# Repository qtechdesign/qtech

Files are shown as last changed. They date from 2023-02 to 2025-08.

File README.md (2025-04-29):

## [FPS | Frost Protection System](https://qtech.hr/en/pages/sustav)

Frost

## Mission

The mission of the Frost Protection System (FPS) is to enable sustainable food and biosystem production through the integration of software and hardware solutions. FPS enables farmers to maximize their yields while minimizing costs by collecting system, time, and production data from various micro-locations and using smart analytics to improve production characteristics. With its focus on the user, continuous improvement, and technical innovation, FPS is uniquely positioned for rapid growth. 

We strive to foster development and create an innovative work environment through the implementation of new business process management systems. We also aim to adopt an agile scrum methodology throughout the entire life cycle of FPS. 

We are committed to continuously creating innovative technical solutions that improve our system. We also strive to use new technologies in a way that positively impacts our global climate.

## Vision

Our vision for the Frost Protection System (FPS) is to create an open source platform that enables efficient, sustainable and environmentally-friendly food production by leveraging innovative technologies. We strive to empower farmers, researchers, and consumers to make informed decisions about their food production and consumption by providing them with access to real-time data on weather conditions and frost protection systems. Through collaboration, we will continue to develop our platform and create a future where food production is both efficient and sustainable.

frost problem

## Motivation

In the past five years, climate change analysis and monitoring of the open-air food production cycle have revealed an increased occurrence of early spring frosts, which has a significant impact on crop yields. Frost events often result in complete yield losses for the upcoming season, which cannot be fully covered by crop insurance. Therefore, active measures to protect and reduce the risk of food production are necessary. One such protective measure is a frost protection system (through irrigation) based on the phenomenon of water anomaly, wherein energy is released when water changes from liquid to solid state. This energy is used to maintain flower and fruit temperatures between 0-2°C. During such protection of crops, an ice crust forms over flowers and fruits with temperature at 0°C that protects them through insulation effect. Modern frost protection systems employ technology to create air saturated with moisture (100% relative humidity) within the protected microclimate that results in significant savings in water requirements during protection since it eliminates evaporation and saves energy required for maintaining thin layer ice crystals at 0°C. Further advancement in technology requires dynamic operation model for the system with varying intensity of irrigation depending on current weather conditions. The reason behind this requirement is to maintain crystal structure of ice (transparent ice) under optimal water consumption throughout night for protecting fruits from negative external temperatures. Parameters that could affect crystal structure of ice are temperature, humidity, wind and intensity of irrigation with droplet size being considered as well. The main objective of this project is to analyze influence parameters on thickness and transparency of protective ice constructions. The obtained results would serve as basis for development advanced management system for frost protection as well as new types sprayers with variable intensity irrigation

# System description

technology FPS

## Multisensor node

The Frost Protection System (FPS) Multisensor is a device designed to provide real-time data on weather conditions and frost protection systems. The device features an integrated solar regulator for 12V battery charging, and operates on 5V power. It can collect data from multiple sensors every 3 minutes, and can also be set to sleep mode between readings. The Multisensor is optimized to consume low amounts of power, making it suitable for use in low voltage devices (above 12V). With its user-friendly interface and easy setup, the FPS Multisensor is the perfect solution for monitoring weather conditions and improving yields.

## Communication device

The Frost Protection System (FPS) Communication Device is a secure and reliable gateway that enables the transmission of data between nodes and the cloud. It uses a private LoRa network to provide wireless communication over a radius of up to 10 km, depending on local radio equipment regulations. This device can be easily installed in any micro-location, and it allows farmers to maximize their yields while minimizing costs by collecting system, time, and production data from various micro-locations. With its focus on user experience, technical innovation, and continuous improvement, FPS Communication Device is uniquely positioned for rapid growth.

## Cloud device

The Frost Protection System (FPS) Cloud Device is a comprehensive microclimate solution for agricultural production. The device collects and stores data from various micro-locations, such as temperature, humidity, light intensity, and soil moisture, to provide farmers with real-time insights into their production environment. The device is powered by a secure cloud platform that is compliant with GDPR regulations and designed for optimal cyber security. Data is collected and transmitted securely using encrypted protocols to ensure that the data is not intercepted or tampered with during transmission. With its user-friendly interface and intuitive analytics, FPS Cloud Device allows farmers to make informed decisions about their crop production in order to maximize yields while minimizing costs.

## [PIP 2.0](https://qtech.hr/en/products/pip-pulsator-2-0)

PIP 2.0

PIP 2.0 sprayer kit is the best ratio of water energy consumption and rainfall efficiency on the protected surface of the frost protection system. The sprayer has a rainfall range of 5 meters at a pressure of 1 bar (water column 10 m). Uniform water flow in the range of 1-4 bar (water column 10--40m). Pulsating sprayer PIP 2.0 ensures a constant rainfall intensity in the range of 1.2-2.0 mm / m2 / h (depending on the installation microlocation and the design of the frost protection system, a grid on which pulsators are placed is defined).

## Fog

fog

Introducing hot air into the system can produce a fog, but it depends on the specific system and the conditions in which the hot air is introduced. In a frost protection system, the goal is to create a microclimate with 100% relative humidity to protect crops from frost damage. This is typically achieved by using irrigation to create a mist or fog that surrounds the crops and maintains the temperature above freezing. If hot air is introduced into the system, it can raise the temperature and reduce the relative humidity, which would make it less effective at protecting crops from frost. 

Introducing the underground hot air at 100% relative humidity (RH) and a temperature around 8°C into an orchard microclimate with -10°C and 95% RH would create a fog. The hot air would cause the temperature in the orchard to rise, and the high humidity would cause the air to reach 100% relative humidity. As the air temperature rises and the humidity increases, the difference between the air temperature and the dew point temperature will decrease, which will cause the air to cool to its dew point temperature. This cooling process will cause the water vapor in the air to condense into droplets, creating a fog.

The fog would help to protect the crops from frost damage by maintaining a higher temperature around the crops, and by creating a protective layer of ice on the crops. The fog would also help to maintain a high relative humidity, which would prevent water droplets from evaporating before they reach the crops.

However, it's important to note that the success of this method would depend on the specific system, weather conditions, and the type of crops you are protecting. It would be best to contact us to discuss possible system integration.

# [Drvoplast | Maslačak](https://drvoplast.com/)

Maslačak is a web platform developed by Qtech in partnership with FMENA and the University of Zagreb. The platform aims to increase the competitiveness of production in the Republic of Croatia by applying advanced technologies, IRI activities, and establishing high standards of environmental acceptability of production.

Through the use of innovative technology, the platform aims to improve the efficiency of the agricultural sector and promote sustainable agricultural production. This will be achieved through the use of advanced technologies such as precision farming and weather forecasting, as well as the implementation of R&D activities to optimize crop yields and reduce environmental impact.

The platform also aims to establish high standards of environmental acceptability of production, which will indirectly promote sustainable agricultural production and more efficient operations of the agricultural sector.

In addition to this, Maslačak also accepts donations in Bitcoin, the address for donations is bc1q2pds7sj3per9le4362v3vu43dxucjh5vjkg9mc

The platform is aligned with the goal of [FSB | R&D](https://trello.com/b/gbMGnvT7/fsb-rd) which is to research and develop new technologies and methods to improve the agricultural sector.

Maslačak

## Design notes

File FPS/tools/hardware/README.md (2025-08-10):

# Hardware directory

Contents
- `PCB` — quick index for PCB projects, build, and assembly notes
- `Calibration.md` — photos link and calibration checklists
- `FPS_v3.0/` — current controller v4.0 and MPPT v3.0 Altium projects
- `FPS_v2.0/` — legacy designs and outputs
- `3D model/` — mechanical STEP and related assets

Quick links
- Controller project: `FPS_v3.0/WS_QTD_v4.0/WS_QTD_v4.0.PrjPcb`
- MPPT project: `FPS_v3.0/WS_MPPT_Board/WS_MPPT_Board.PrjPcb`
- Calibration album: https://photos.app.goo.gl/msPYUroQLh4XpNES6

Notes
- See `PCB` for DRC, fabrication, and assembly details
- See `NOTE_CHANGE_PIN.txt` for pin changes applied in Qtech 3.0

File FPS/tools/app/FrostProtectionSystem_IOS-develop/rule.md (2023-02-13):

{
  "rules": {
    "users" : {
      "$user_id": {
        ".read": "$user_id == auth.uid",
        ".write": "$user_id == auth.uid && newData.hasChildren(['user_name', 'email'])",
        "user_name": {
          ".validate": "newData.isString() && newData.val() != ''"
        },
        "email": {
          ".validate": "auth.token.email === newData.val()",
        },
        "gateways": {
          ".validate": "newData.hasChildren()",
          "$gateway_id": {
          	".validate": "newData.parent().parent().parent().parent().child('gateways').child($gateway_id).child('owner').val() == $user_id &&
            newData.hasChildren(['name'])",
            "name": {
              ".validate": "newData.val() == newData.parent().parent().parent().parent().parent().child('gateways').child($gateway_id).child('name').val()"
            },
            "devices": {
              ".validate": "newData.hasChildren()",
              "$device_id": {
                ".validate": "newData.parent().parent().parent().parent().parent().parent().child('gateways').child($gateway_id).child('devices').child($device_id).exists() && newData.isString()"
              }
            },
            "$other": { ".validate": false }
          }
        },
        "$other": { ".validate": false }
      }
    },
    "gateways" : {
      "$gateway_id": {
        ".read": "auth.uid == data.child('owner').val()",
        ".write": "(newData.hasChildren(['name','owner'])
        && (!data.child('owner').exists()
            || data.child('owner').val() == ''
            || data.child('owner').val() == auth.uid
            || newData.child('owner').val() == auth.uid))
        || !newData.exists()
        		&& data.child('owner').val() == auth.uid
        		&& !newData.parent().parent().child('users').child(data.child('owner').val()).child('gateways').child($gateway_id).exists() ",
        "public_key": { ".validate": "newData.isString()" },
        "name": { ".validate": "newData.isString()" },
        "GPS": {
          ".validate": "newData.hasChildren(['lat','long'])",
           "lat": { ".validate": "newData.isNumber()" },
           "long": { ".validate": "newData.isNumber()" },
        },
        "owner": {
          ".validate": "newData.parent().parent().parent().child('users').child(newData.val()).child('gateways').child($gateway_id).exists() &&
          (!data.exists() || !newData.parent().parent().parent().child('users').child(data.val()).child('gateways').child($gateway_id).exists())"
        },
        "command": { ".validate": "newData.isString()" },
        "devices": {
          ".validate": "newData.hasChildren()",
          "$device_id": {
            ".validate": "newData.hasChildren()",
            "lora_id": { ".validate": true },
            "TS": { ".validate": true },
            "name": { ".validate": true },
            "on": { ".validate": true },
            "GPS": { ".validate": true },
            "$other": { ".validate": false },
          }
        },
        "last_login": { ".validate": true },
        "$other": { ".validate": false },
      }
    },
    "devices" : {
      ".read": "auth != null",
      ".write": "auth != null",
      "$device_id": {
        ".validate": "newData.hasChildren()",
        "GPS": {
          ".validate": "newData.hasChildren(['lat','long'])",
           "lat": { ".validate": "newData.isNumber()" },
           "long": { ".validate": "newData.isNumber()" },
        },
        "name": { ".validate": "newData.isString()" },
        "lora_id": { ".validate": true },
        "owner": {
          ".validate": "newData.parent().parent().parent().child('gateways').child(newData.val()).child('devices').child($device_id).exists() &&
          (!data.exists() || !newData.parent().parent().parent().child('gateways').child(newData.val()).child('devices').child($device_id).exists())"
        },
        "owner_public_key": { ".validate": "newData.isString()" },
        "public_key": { ".validate": "newData.isString()" },
        "current_data": {
          ".validate": "newData.hasChildren()"
        },
        "$other": { ".validate": false },
      }
    },
  	"device_logs" : {
      ".read": "auth != null",
      ".write": "auth != null",
      "$device_id": {
        ".indexOn": ["TS"]
			}
    },
    "key": {
      ".read": true,
      ".write": false,
    },
    "$other": {
      ".read": false,
      ".write": false
    }
  }
}

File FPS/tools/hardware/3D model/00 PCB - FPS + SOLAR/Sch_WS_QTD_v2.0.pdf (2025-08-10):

GND | R¹ | 1%10k

# EBYTE

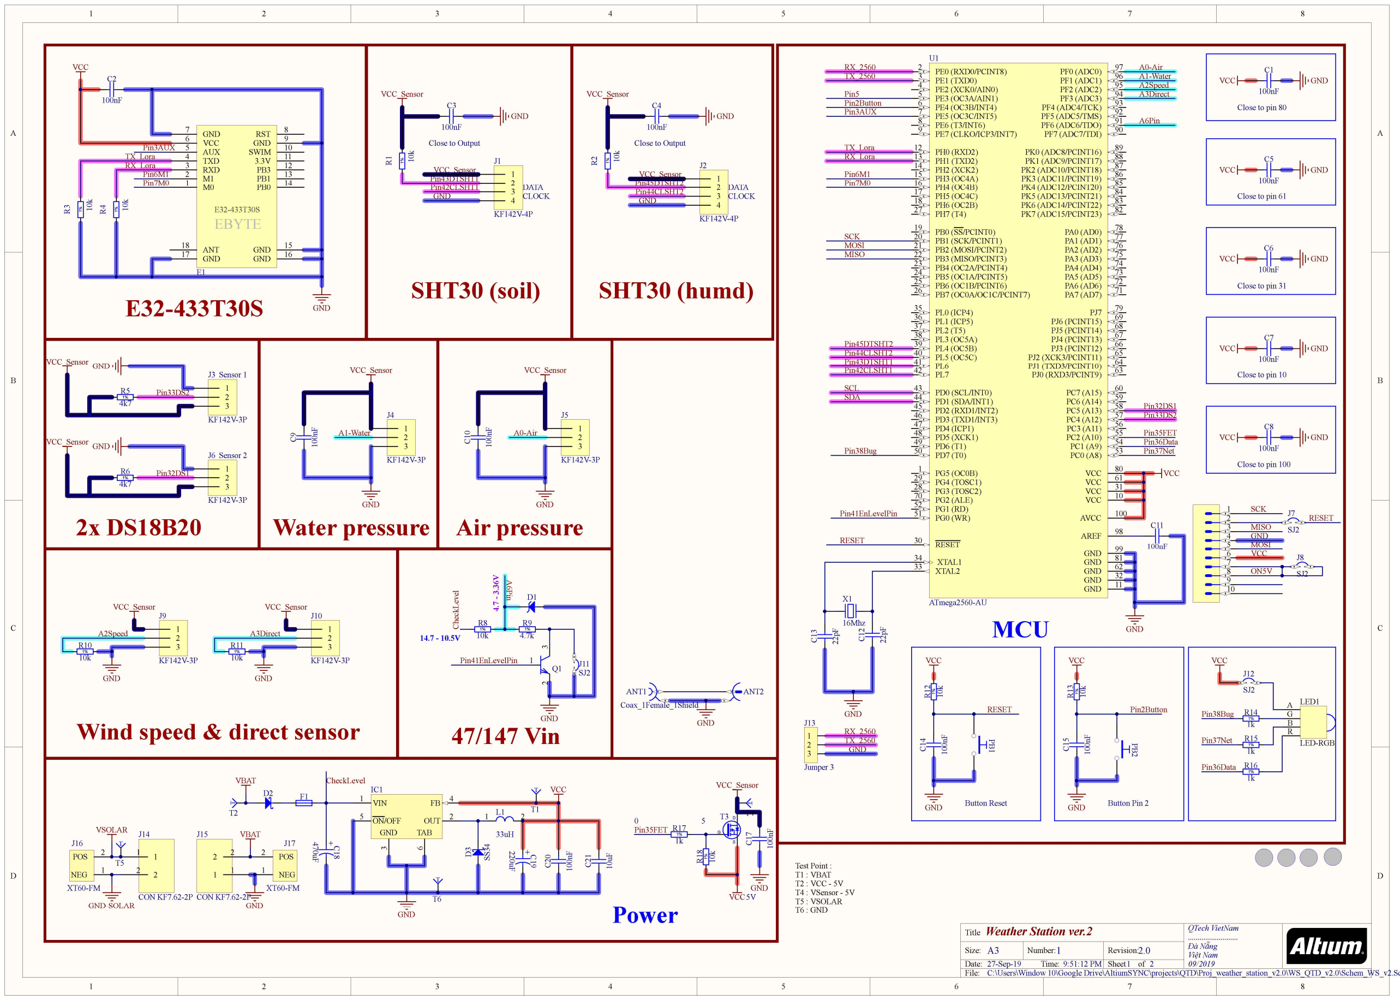
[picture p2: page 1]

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
QTech VietNam
Đà Nẵng
Việt Nam
2 09/2019

## Weather Station ver.2

1 2.0
27-Sep-19 | 9:51:12 PM
C:\Users\Window 10\Google Drive\AltiumSYNC\projects\QTD\Proj_weather_station_v2.0\WS_QTD_v2.0\Schem_WS_v2.SchDoc

Title

Size: | Number:
Date:
File:

Revision:
Time: | Sheet | of

A3

Pin3AUX

Pin6M1
Pin7M0

GND

VCC
C2
100nF 1% | R⁴ | 1%10k R³ | 10k

# E32-433T30S

TX_Lora
RX_Lora
PJ0 (RXD3/PCINT9) | 63
AVCC | 100
VCC | 31
GND | 11 GND | 32
GND | 81

PG5 (OC0B) 1

PD2 (RXD1/INT2) 45

RESET 30

PA4 (AD4) | 74
PA7 (AD7) | 71
PA5 (AD5) | 73
VCC | 80

XTAL1 34

PC1 (A9) | 54 PC2 (A10) | 55 PC3 (A11) | 56 PC4 (A12) | 57 PC5 (A13) | 58
PJ5 (PCINT14) | 68 PJ6 (PCINT15) | 69
AREF | 98

PD1 (SDA/INT1) 44

PB6 (OC1B/PCINT6) 25

PD3 (TXD1/INT3) 46
PD4 (ICP1) 47
PD5 (XCK1) 48
PD6 (T1) 49
PD7 (T0) 50
PF1 (ADC1) | 96
PF2 (ADC2) | 95
PC0 (A8) | 53
PA3 (AD3) | 75
PF4 (ADC4/TCK) | 93
PF5 (ADC5/TMS) | 92
PF6 (ADC6/TDO) | 91
PF7 (ADC7/TDI) | 90
PG0 (WR) 51 | PG1 (RD) 52 | PG2 (ALE) 70
PA6 (AD6) | 72

PD0 (SCL/INT0) 43

PH2 (XCK2) 14

PL2 (T5) 37
PL3 (OC5A) 38
PL4 (OC5B) 39
PL5 (OC5C) 40
PL6 41

VCC 10

XTAL2 33

PG3 (TOSC2) 28

PB5 (OC1A/PCINT5) 24

PF3 (ADC3) | 94
PA1 (AD1) | 77
PA2 (AD2) | 76

PE4 (OC3B/INT4) 6
PE5 (OC3C/INT5) 7
PE6 (T3/INT6) 8
PE7 (CLKO/ICP3/INT7) 9
PJ3 (PCINT12) | 66
PK5 (ADC13/PCINT21) | 84 PK4 (ADC12/PCINT20) | 85 PK3 (ADC11/PCINT19) | 86

PB2 (MOSI/PCINT2) 21
PB3 (MISO/PCINT3) 22
PB4 (OC2A/PCINT4) 23
PA0 (AD0) | 78
GND | 99
PK2 (ADC10/PCINT18) | 87
PJ2 (XCK3/PCINT11) | 65
PJ1 (TXD3/PCINT10) | 64

PG4 (TOSC1) 29

PF0 (ADC0) 97

PE3 (OC3A/AIN1) 5

PE2 (XCK0/AIN0) 4

PE1 (TXD0) 3

PE0 (RXD0/PCINT8) 2

PB7 (OC0A/OC1C/PCINT7) 26

PB1 (SCK/PCINT1) 20 PB0 (SS/PCINT0) 19

PH1 (TXD2) 13

PJ7 | 79
PJ4 (PCINT13) | 67
GND | 62
VCC | 61

PL7 42

PH0 (RXD2) 12

PH3 (OC4A) 15
PH4 (OC4B) 16
PH5 (OC4C) 17
PH6 (OC2B) 18
PH7 (T4) 27 | PK6 (ADC14/PCINT22) | 83
PK1 (ADC9/PCINT17) | 88 PK0 (ADC8/PCINT16) | 89

PL0 (ICP4) 35

PK7 (ADC15/PCINT23) 82

PL1 (ICP5) 36

PC6 (A14) | 59 PC7 (A15) | 60

U1

ATmega2560-AU

GND

VCC

X1

16Mhz C¹³ | 22pF | C¹² | 22pF

GND

C11

100nF

C1

100nF

C5

100nF

C6

100nF

C7

100nF

C8

100nF

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
Close to pin 80

Close to pin 61

Close to pin 31

Close to pin 10

Close to pin 100
RESET | C¹⁴ | 100nF ¹% R¹² 10k

VCC

GND

RESET

Button Reset | C¹⁵ | 100nF ¹% R¹³ 10k

VCC

GND Button Pin 2

Pin2Button

A0-Air
A1-Water
A2Speed
A3Direct

TX_Lora
RX_Lora

SCK
MOSI
MISO

RX_2560
TX_2560

VCC_Sensor GND

Pin32DS1
1%

R6
4k7

Pin3AUX

Pin5

Pin6M1

VCC_Sensor GND

Pin33DS2
1%

R5
4k7

# 2x DS18B20

VCC_Sensor

Pin42CLSHT1

Pin43DTSHT1

GND

DATA
CLOCK

# SHT30 (soil)

C3

100nF

VCC_Sensor

Close to Output

Sensor 1

Sensor 2

# Air pressure

# Wind speed & direct sensor

VCC_Sensor | VCC_Sensor
GND | GND

1%

R11
10k

1%

R10
10k
A2Speed | A3Direct

1%

R9
4.7k

1%

R8

10k A6Pin

# 47/147 Vin

14.7 - 10.5V | 4.7 ⁻ 3.36V

# MCU

GND | D³ | SS³⁴ | C²⁰ | 100nF

1 2

L1

33uH

+C18 470uF | +C19 220uF

VCC D2

VBAT

F1

# Power

VBAT

GND

Pin2Button PB1 | PB2

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
1k 1% R¹⁸ 10k

1%

R17
1k

VCC_Sensor

VCC

Pin7M0

Pin32DS1
Pin33DS2

Pin42CLSHT1

Pin43DTSHT1

# Water pressure

A1-Water

VCC_Sensor

GND

Pin38Bug | Pin37Net

Pin35FET

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
ON5V

RESET

SCK

GND

MISO

VCC

MOSI

D

S

G

T3

5V

0 5

GND

TX_2560

RX_2560

A

B

G

R

LED1

LED-RGB

J12

SJ2

Pin38Bug

Pin37Net

VSOLAR

GND-SOLAR | C²¹ | 10uF

1 3 2

Q1

GND

Pin41EnLevelPin

J7

SJ2

J8

SJ2

VCC_Sensor

Pin44CLSHT2

Pin45DTSHT2

GND

DATA
CLOCK

# SHT30 (humd)

C4

100nF

VCC_Sensor

Close to Output R² 1%10k

GND

Pin44CLSHT2

Pin45DTSHT2

A0-Air

VCC_Sensor

GND C⁹ | 100nF | C¹⁰ | 100nF

A6Pin

D1

SCL
SDA

GND 7
VCC 6
AUX 5
TXD 4
RXD 3
M1 2
M0 1
RST | 8
GND | 9
SWIM | 10
3.3V | 11
PB3 | 12
PB1 | 13
PB0 | 14

ANT 18

GND 17 | GND | 15
| GND | 16

E32-433T30S

E1

1

1

2

2

J15

CON KF7.62-2P

VIN 1

ON/OFF 5 | OUT 2

GND3

FB 4

TAB6

IC1

1

1

2

2

J14

CON KF7.62-2P

T

T1

T

T5

T

T6 | T T4

Test Point :
T1 : VBAT
T2 : VCC - 5V
T4 : VSensor - 5V
T5 : VSOLAR
T6 : GND

1
2
3

J13

Jumper 3

POS | 2
NEG | 1

J16

XT60-FM

POS 2

NEG 1

J17

XT60-FM | C¹⁷ | 100nF

GND T
T2

ANT1
Coax_1Female_1Shield

ANT2

1
2
3
4

J1

KF142V-4P

1
2
3
4

J2

KF142V-4P

1
2
3

J3

KF142V-3P

1
2
3

J6

KF142V-3P

1
2
3

J4

KF142V-3P

1
2
3

J5

KF142V-3P

1
2
3

J9

KF142V-3P

1
2
3

J10

KF142V-3P

CheckLevel | CheckLevel

J11
SJ2

Pin35FET

Pin41EnLevelPin

GND

Pin36Data

Pin36Data

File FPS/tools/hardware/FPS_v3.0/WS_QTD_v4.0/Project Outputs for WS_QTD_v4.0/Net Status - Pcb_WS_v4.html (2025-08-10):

Altium customize

# Net Status Report

Date: | | 09-Jan-21
Time: | | 7:13:06 PM
Elapsed Time: | | 00:00:00
Filename: | | D:\Google Drive\AltiumSYNC\projects\QTD\Proj_weather_station_v4.0\WS_QTD_v4.0\Pcb_WS_v4.PcbDoc
Units: | | mmmils

Nets | Layer | Length
ANT_M | Signal Layers Only | 0mils
ANT_M1 | Signal Layers Only | 0mils
AREF | Signal Layers Only | 186.821mils
AUX | Signal Layers Only | 191.795mils
BAT-VSEN | Signal Layers Only | 0mils
BAT-VSEN-Q | Signal Layers Only | 107.992mils
CLOSE1 | Signal Layers Only | 0mils
CLOSE2 | Signal Layers Only | 0mils
COM1 | Signal Layers Only | 0mils
COM2 | Signal Layers Only | 0mils
DATA-AP1 | Signal Layers Only | 188.941mils
DATA-AP2 | Signal Layers Only | 113.749mils
DATA-DS1 | Signal Layers Only | 113.749mils
DATA-DS2 | Signal Layers Only | 113.749mils
GND | Signal Layers Only | 315.593mils
GND-SOLAR | Signal Layers Only | 0mils
LED | Signal Layers Only | 186.821mils
M0 | Signal Layers Only | 108.775mils
M1 | Signal Layers Only | 186.821mils
MISO | Signal Layers Only | 188.941mils
MOSI | Signal Layers Only | 107.992mils
NetD2_1 | Signal Layers Only | 0mils
NetD4R1_2 | Signal Layers Only | 0mils
NetD4R2_2 | Signal Layers Only | 0mils
NetIC2R1_1 | Signal Layers Only | 0mils
NetIC2R2_1 | Signal Layers Only | 0mils
NetLED1_1 | Signal Layers Only | 0mils
NetLED2R1_1 | Signal Layers Only | 0mils
NetLED2R2_1 | Signal Layers Only | 0mils
NetQ2_1 | Signal Layers Only | 0mils
NetQ3R1_1 | Signal Layers Only | 0mils
NetQ3R2_1 | Signal Layers Only | 0mils
NetR7_2 | Signal Layers Only | 0mils
NetU1_19 | Signal Layers Only | 108.775mils
NetU1_22 | Signal Layers Only | 181.456mils
NetU2_10 | Signal Layers Only | 0mils
NetU2_11 | Signal Layers Only | 0mils
NetU2_12 | Signal Layers Only | 0mils
NetU2_13 | Signal Layers Only | 0mils
NetU2_14 | Signal Layers Only | 0mils
OPEN1 | Signal Layers Only | 0mils
OPEN2 | Signal Layers Only | 0mils
P12V-BAT | Signal Layers Only | 0mils
P16V-SOLAR | Signal Layers Only | 0mils
P5V-Main | Signal Layers Only | 1539.358mils
P5V-SEN | Signal Layers Only | 0mils
RESET-E32 | Signal Layers Only | 191.795mils
RL-CTL1 | Signal Layers Only | 191.795mils
RL-CTL2 | Signal Layers Only | 108.775mils
RL-CTR1 | Signal Layers Only | 0mils
RL-CTR2 | Signal Layers Only | 0mils
RST-E32 | Signal Layers Only | 0mils
RST_MCU | Signal Layers Only | 103.409mils
RXD-E32 | Signal Layers Only | 103.409mils
RXM | Signal Layers Only | 181.456mils
SCK | Signal Layers Only | 113.749mils
TXD-E32 | Signal Layers Only | 181.456mils
TXM | Signal Layers Only | 107.992mils
WAKE | Signal Layers Only | 188.941mils
XTAL1 | Signal Layers Only | 107.992mils
XTAL2 | Signal Layers Only | 188.941mils

Back to top

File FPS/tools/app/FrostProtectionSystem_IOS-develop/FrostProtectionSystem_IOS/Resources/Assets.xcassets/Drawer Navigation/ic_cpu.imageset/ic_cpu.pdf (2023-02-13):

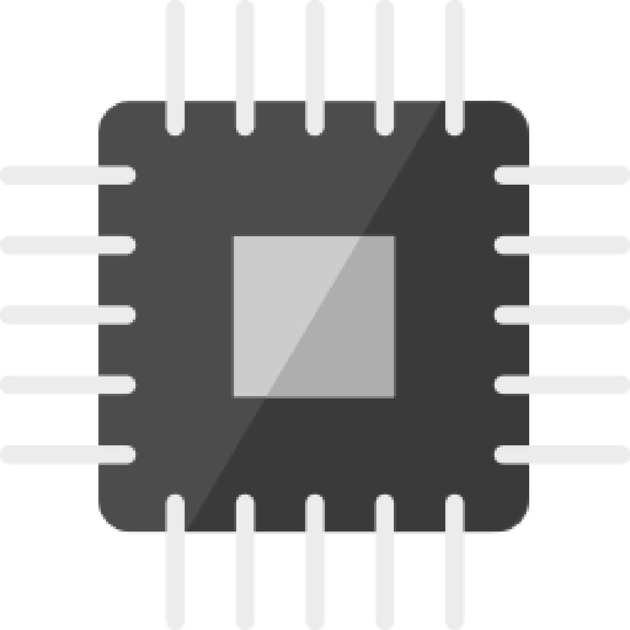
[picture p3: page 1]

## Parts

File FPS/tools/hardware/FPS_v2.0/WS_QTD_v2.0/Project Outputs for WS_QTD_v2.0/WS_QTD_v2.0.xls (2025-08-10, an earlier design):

Comment | Description | Designator | Footprint | LibRef | Quantity | 6 | Check
Coax_1Female_1Shield |  | ANT1 | HUBER-SUHNER_85 SMA-50-0-101/111 NE | HUBER-SUHNER_85_SMA-50-0-101/111_NE | 1 | 6 | ok
U.FL |  | ANT2 | HIROSE_U.FL-R-SMT-1(10) | HIROSE_U.FL-R-SMT-1(10) | 1 | 6 | ok
100nF | Non-polarised capacitor | C1, C2, C3, C4, C5, C6, C7, C8, C9, C10, C11, C14, C15, C17, C20 | CAPC1608X87N | CC0603_100NF_50V_10%_X7R | 15 | 90 | ok
22pF | Non-polarised capacitor | C12, C13 | CAPC1608X87N | CC0603_22PF_50V_5%_NP0 | 2 | 12 | ok
470uF | Polarised capacitor | C18 | CAPAE1030X1020N | CAE1030-1020_470UF_25V_20% | 1 | 6 | ok
220uF | Polarised capacitor | C19 | CAPMP6032X280N | CTE6032-28_100UF_6.3V_10%_LESR0075 | 1 | 6 | ok
10uF | Non-polarised capacitor | C21 | CAPC2012X135N | CC0805_10UF_16V_10%_X5R | 1 | 6 | ok
BZV55-B5V1 | Zener Diode | D1 | DIOMELF3515N | BZV55-B5V1 | 1 | 6 | ok
SS16 | Schottky Diode | D2 | DIOM5127X229N | SS16 | 1 | 6 | ok
SS34 | Schottky Diode | D3 | DIOM5127X229N | SS16 | 1 | 6 | ok
E32-T30S | Lora Ebyte E32-T30S Module | E1 | E32-433T30S | E32-433T30S | 1 | 6
140mA-60V | Fuse | F1 | FUSRC4632X90N | FUSR1812_TYCO-MINISMDC014F | 1 | 6 | ok
HOLE |  | HOLE1, HOLE2, HOLE3, HOLE4 | HOLE M3 | HOLE M3 | 4 | 24
LM2596 |  | IC1 | TO263-5 | LM2596-5V | 1 | 6 | ok
KF142V-4P | CON KF142V-4P-5.08 | J1, J2 | CON KF142V-4P-5.08 | CON KF142V-4P-5.08 | 2 | 12 | ok
KF142V-3P | CON KF142V-3P-5.08 | J3, J4, J5, J6, J9, J10 | CON KF142V-3P-5.08 | CON KF142V-3P-5.08 | 6 | 36 | ok
SJ2 | Solder Jump2 | J7, J8, J11, J12 | SJ2 | SJ2 | 4 | 24
Jumper 3 | Jumper 3 | J13 | JP3 | JP3 | 1 | 6
CON KF7.62-2P |  | J14, J15 | CON KF7.62-2P | CON KF7.62-2P | 2 | 12 |  | lấy ET-SDC
XT60-FM |  | J16, J17 | XT60-FM | XT60-FM | 2 | 12
Header 10 | Connector 10 Male | JTAG1 | 3M_N2510-6002RB | 3M_N2510-6002RB | 1 | 6 | ok
33uH |  | L1 | L_SMD | L_SMD 33uH | 1 | 6 | ok
LED-RGB |  | LED1 | LED-5MMRGBCA | LED-RGB | 1 | 6 | ok
Push Button | Push-Button Switch SPDT | PB1, PB2 | PB_TYCO_FSMSM |  | 2 | 12 | ok
C1815 | Q2SC1815 | Q1 | SOT23 | C1815 | 1 | 6 | ok
10k | Resistor - 1% | R1, R2, R3, R4, R8, R10, R11, R12, R13, R18 | RESC1608X55N | R0603_10K_1%_0.1W_100PPM, R0603_2M_1%_0.1W_100PPM, R0603_160R_1%_0.1W_100PPM | 10 | 60 | ok
4k7 | Resistor - 1% | R5, R6 | RESC1608X55N | R0603_4K7_1%_0.1W_100PPM | 2 | 12 | ok
4.7k | Resistor - 1% | R9 | RESC1608X55N | R0603_1M_1%_0.1W_100PPM | 1 | 6 | ok
1k | Resistor - 1% | R14, R15, R16, R17 | RESC1608X55N | R0603_1K_1%_0.1W_100PPM | 4 | 24 | ok
Test Point | Test Point Round 1x1 mm | T2, T4, T5, T6 | TP1x1r | TP R1x1 | 4 | 24
BSH203 | P-CHANNEL MOSFET WITH DIODE | T3 | SOT95P230X110-3N | BSH203 | 1 | 6 | ok
ATmega2560-AU | 8-bit AVR Microcontroller, 4.5-5.5V, 256KB Flash, 4KB EEPROM, 8KB SRAM, 86 GPIO pins, 100-pin TQFP, Industrial Grade (-40°C to 85°C), Pb-Free | U1 | TQFP100L | ATmega2560-AU | 1 | 6 | ok
16Mhz | Crystal, 32.768 KHz, -40 to 85 degC, 3.2 x 1.5 x 0.9 mm SMD | X1 | XT2 | XT2 | 1 | 6 | ok
Dây dài ipex |  |  |  |  |  | 6 | ok
 |  |  |  |  |  |  |  |  | thegioiic | 1245390
 |  |  |  |  |  |  |  |  | linhkien888 | 122500

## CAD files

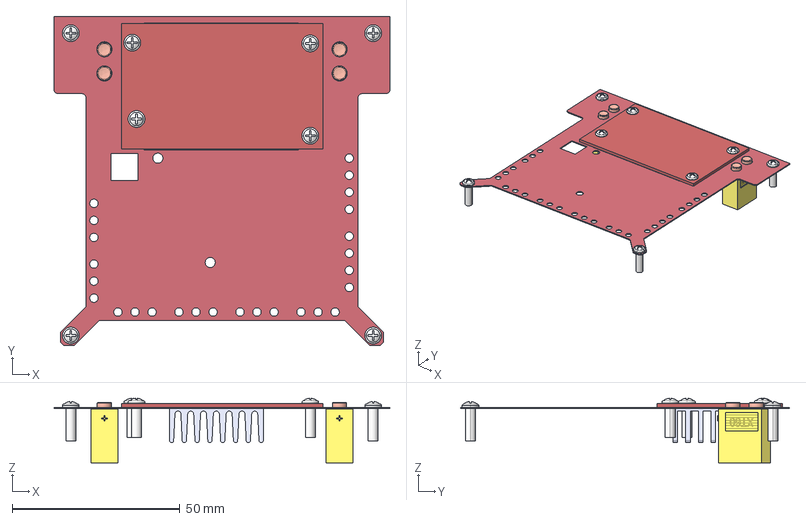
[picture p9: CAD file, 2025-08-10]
FPS/tools/hardware/3D model/00 PCB - FPS + SOLAR/Red_board.step
100.0 x 98.0 x 19.2 mm
User_Library-658-45AB
Screw-3mmX10mm x 8
Extruded
PDB_XT60_PLUG x 4

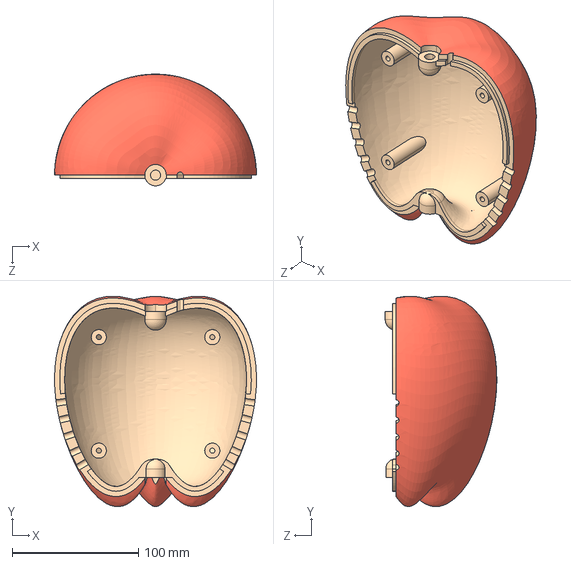
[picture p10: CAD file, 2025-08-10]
FPS/tools/hardware/3D model/Trešnja ABS/Tresnja_L.STEP
160.2 x 166.7 x 88.6 mm

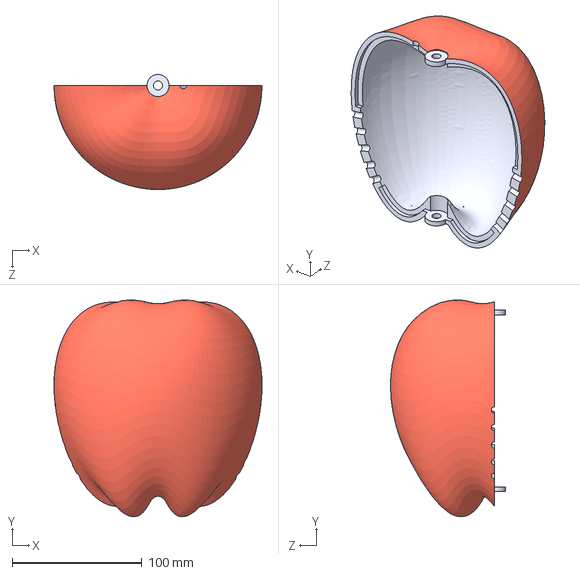
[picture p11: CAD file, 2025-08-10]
FPS/tools/hardware/3D model/Trešnja ABS/Tresnja_D.STEP
160.1 x 166.7 x 88.6 mm

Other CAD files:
FPS/tools/hardware/3D model/Trešnja ABS/Tresnja_D.SLDPRT
FPS/tools/hardware/3D model/Trešnja ABS/Tresnja_D.STL
FPS/tools/hardware/3D model/Trešnja ABS/Tresnja_L.SLDPRT
FPS/tools/hardware/3D model/Trešnja ABS/Tresnja_L.STL

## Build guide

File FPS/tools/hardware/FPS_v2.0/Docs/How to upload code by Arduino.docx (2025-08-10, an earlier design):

Open Arduino IDE and Connect Arduino to computer.

Open File > Examples > 11. ArduinoISP > ArduinoISP

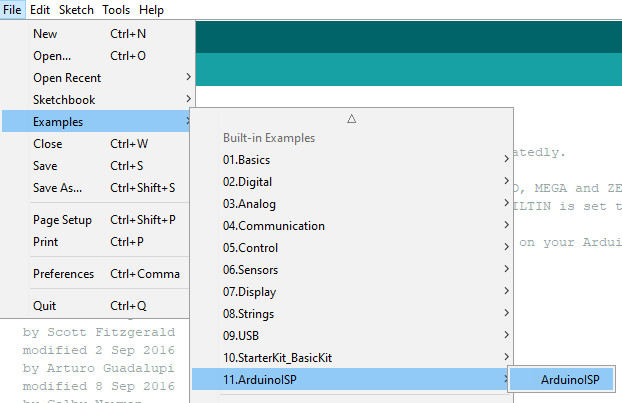
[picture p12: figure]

Choose Board : Arduino Uno and Port COM

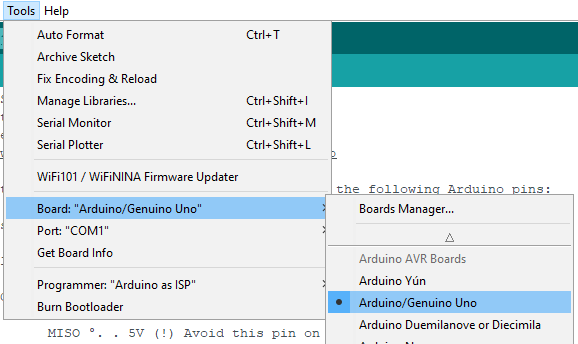
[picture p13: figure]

Upload to Arduino Uno

After upload done

Change Board : Arduino Mega 2560 and Processor : ATmega2560

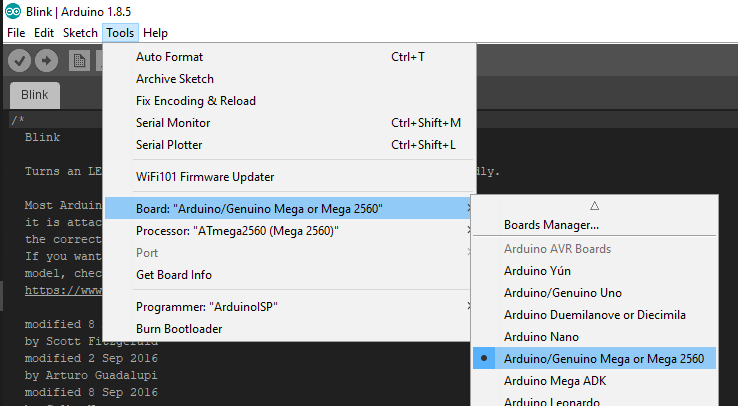
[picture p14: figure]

We use pin 10,11,12,13 (SS,MOSI,MISO,CLK) on Arduino Uno

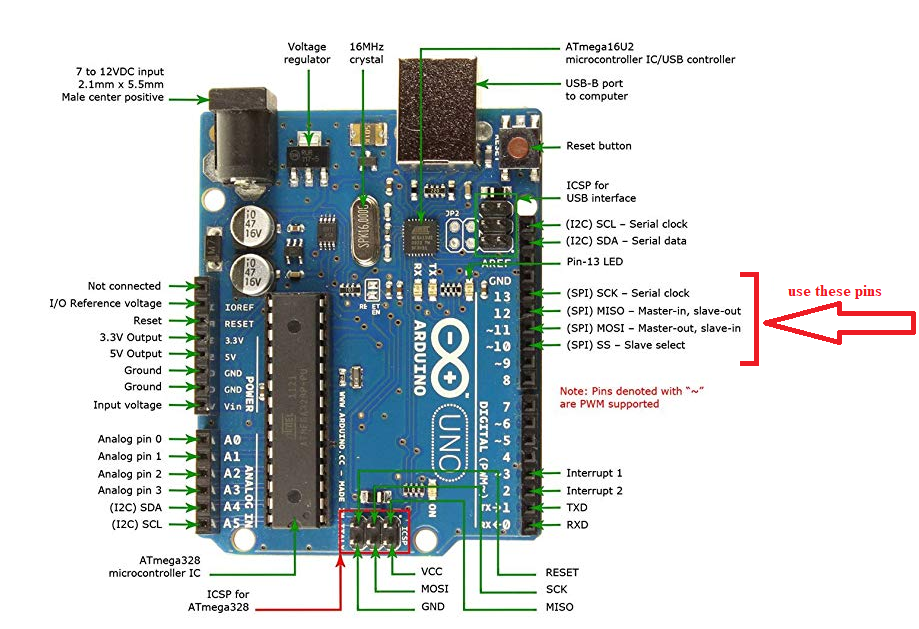
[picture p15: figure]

And connect to pins (ISP Port) on the Sensor Node

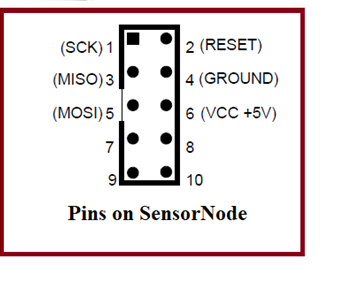
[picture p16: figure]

Connect pin on Arduino Uno to Sensor Node

MOSI ( pin 11 ) > MOSI

MISO ( pin12 ) > MISO

SCK ( pin 13 ) > SCK

SS ( pin 10 ) > RESET

VCC ( 5V ) > VCC

GND > GND

Choose Board : Arduino Mega 2560 and Processor : ATmega2560

Connect Arduino to computer

Choose Programmer : “Arduino as ISP” and Port COM

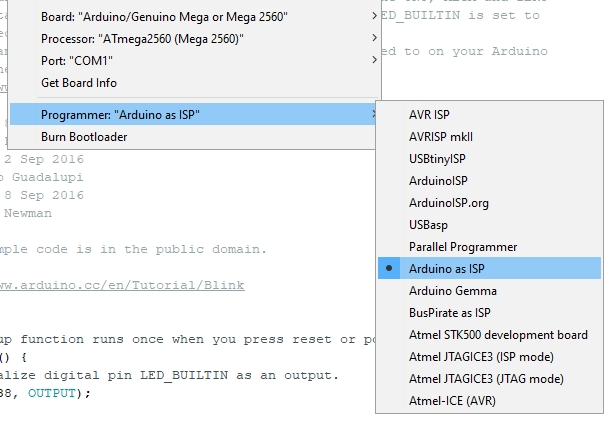
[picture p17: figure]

Then click Burn Bootloader for ATmega2560 on Sensor Node.

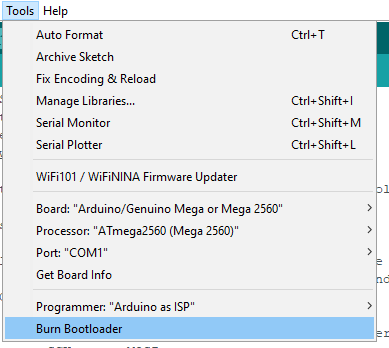
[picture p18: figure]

Wait about 30 seconds to finish

Then, Open Aruidno IDE and open (code).ino file (updated code).

You must remove ATMega328P on Arduino UNO,

be careful, foot of Atmega328 can be broken.

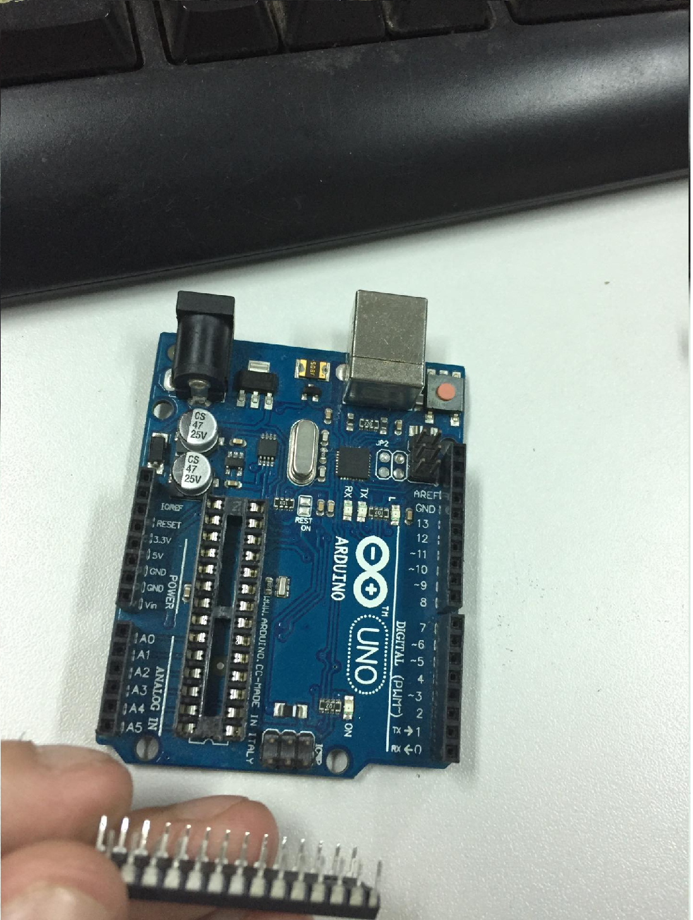
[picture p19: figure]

We use the this Arduino Board without Atmega328P

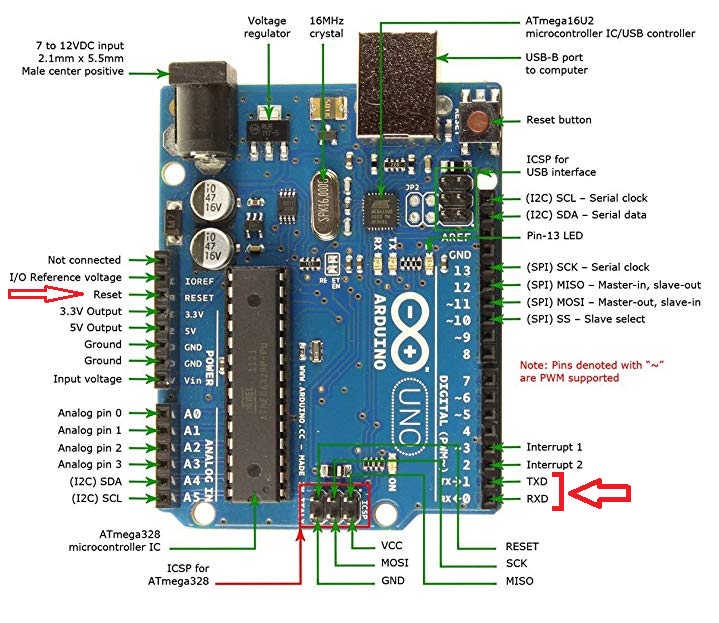
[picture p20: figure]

Connect UART pins to SensorNODE. Look 3 pins below the ISP Port.

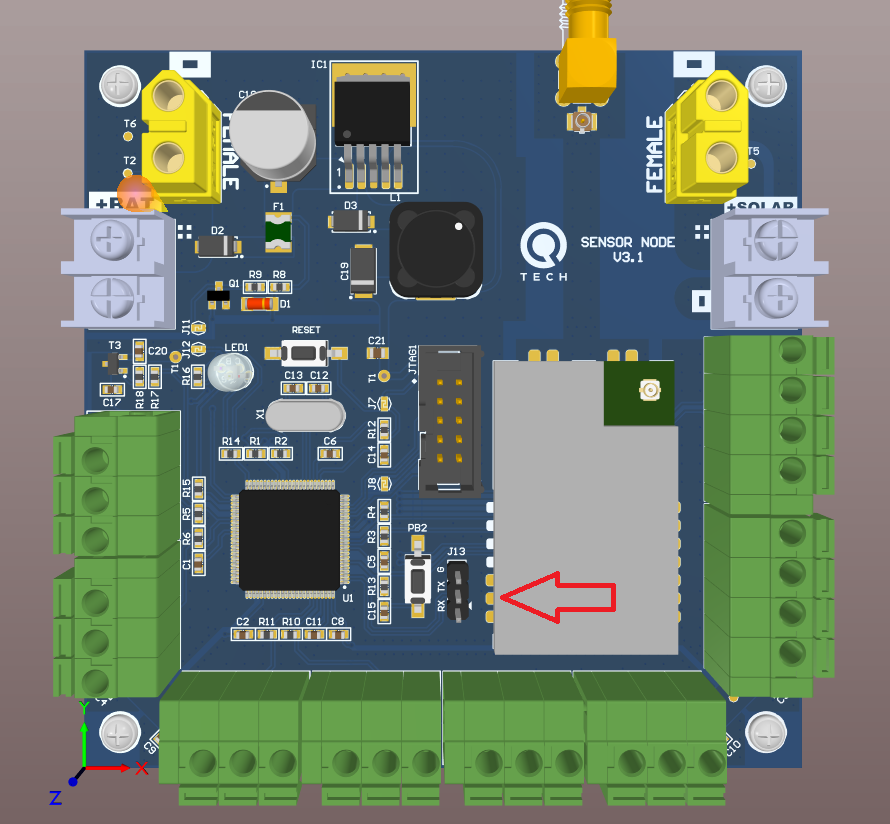
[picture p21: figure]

TX > RX

RX > TX

GND > GND

RESET > RESET (on ISP Port)

5V > 5V (on ISP Port)

Then Upload code to ATMega2560 on SensorNode

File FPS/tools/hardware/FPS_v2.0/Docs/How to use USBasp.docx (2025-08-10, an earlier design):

Follow this video to install driver for USBasp

https://www.youtube.com/watch?v=jgHIFWPUe_M

You can download Zadig at https://zadig.akeo.ie

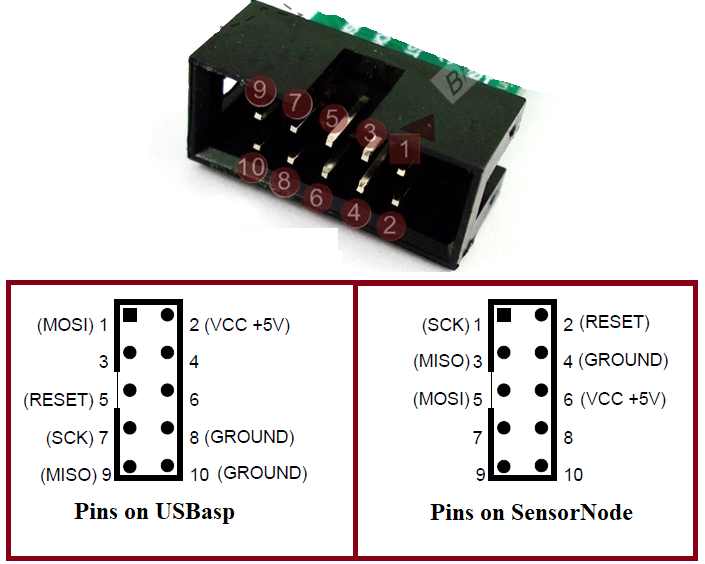
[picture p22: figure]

Connect pin on USBasp to Sensor Node

MOSI > MOSI

MISO > MISO

SCK > SCK

RESET > RESET

VCC > VCC

GND > GND

Open Aruidno IDE and open .ino file (updated code).

Choose Board : Arduino Mega 2560 and Processor : ATmega2560


Connect USBasp to computer

Choose Programmer : USBasp and Port COM

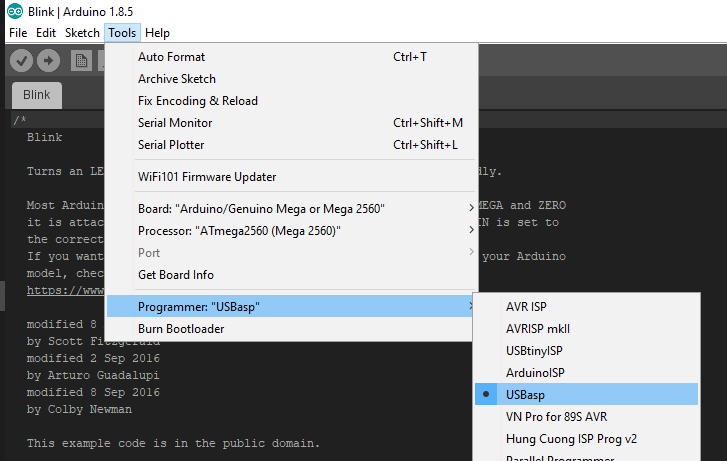
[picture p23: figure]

Then click Upload to loading code for ATmega2560 on Sensor Node.

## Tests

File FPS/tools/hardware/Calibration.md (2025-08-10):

# FPS hardware calibration and validation

Album (photos, setups, results)
- Google Photos: https://photos.app.goo.gl/msPYUroQLh4XpNES6

Scope
- Electrical bring‑up, sensor calibration, RF link checks, and environmental validation for the FPS controller (`WS_QTD_v4.0`) and `WS_MPPT_Board`.

References (design files)
- Controller: `FPS/tools/hardware/FPS_v3.0/WS_QTD_v4.0/WS_QTD_v4.0.PrjPcb`
- MPPT: `FPS/tools/hardware/FPS_v3.0/WS_MPPT_Board/WS_MPPT_Board.PrjPcb`
- Pin changes: `FPS/tools/hardware/FPS_v3.0/NOTE_CHANGE_PIN.txt`
- Datasheets: `FPS/tools/hardware/FPS_v3.0/Docs/` (ATmega2560, DS18B20, E32 LoRa, Air Pressure)

Bench setup
- Power via MPPT output or lab supply; verify polarity and fuse.
- Serial monitor on controller UART; log timestamps and measurements.
- Attach DS18B20 and air‑pressure sensors; connect LoRa module per schematic.

Checklist (bring‑up)
1) Power rails: 5 V and 3.3 V within tolerance; inrush < expected; steady‑state current noted.
2) Clock/reset: controller enumerates; boot banner visible on UART.
3) I/O pins: confirm any remaps per NOTE_CHANGE_PIN.txt.

Checklist (sensor calibration)
- DS18B20: compare to reference thermometer over 0–25 °C; accept ±0.5 °C; record offset if needed.
- Air pressure: compare to calibrated barometer; adjust slope/offset in firmware constants if drift observed.

Checklist (RF link)
- E32‑433T30S / E32‑868T20S: RSSI at 1–10 m line of sight; packet error rate under nominal conditions; antenna keep‑out respected.

Environmental validation
- Cold chamber / outdoor run: correlate measured temperature/humidity with album photos; confirm defog/frost behavior vs. expectations.

Artifacts
- Photos and setup notes: see album above.
- Logs: store alongside test date under project logs if available.

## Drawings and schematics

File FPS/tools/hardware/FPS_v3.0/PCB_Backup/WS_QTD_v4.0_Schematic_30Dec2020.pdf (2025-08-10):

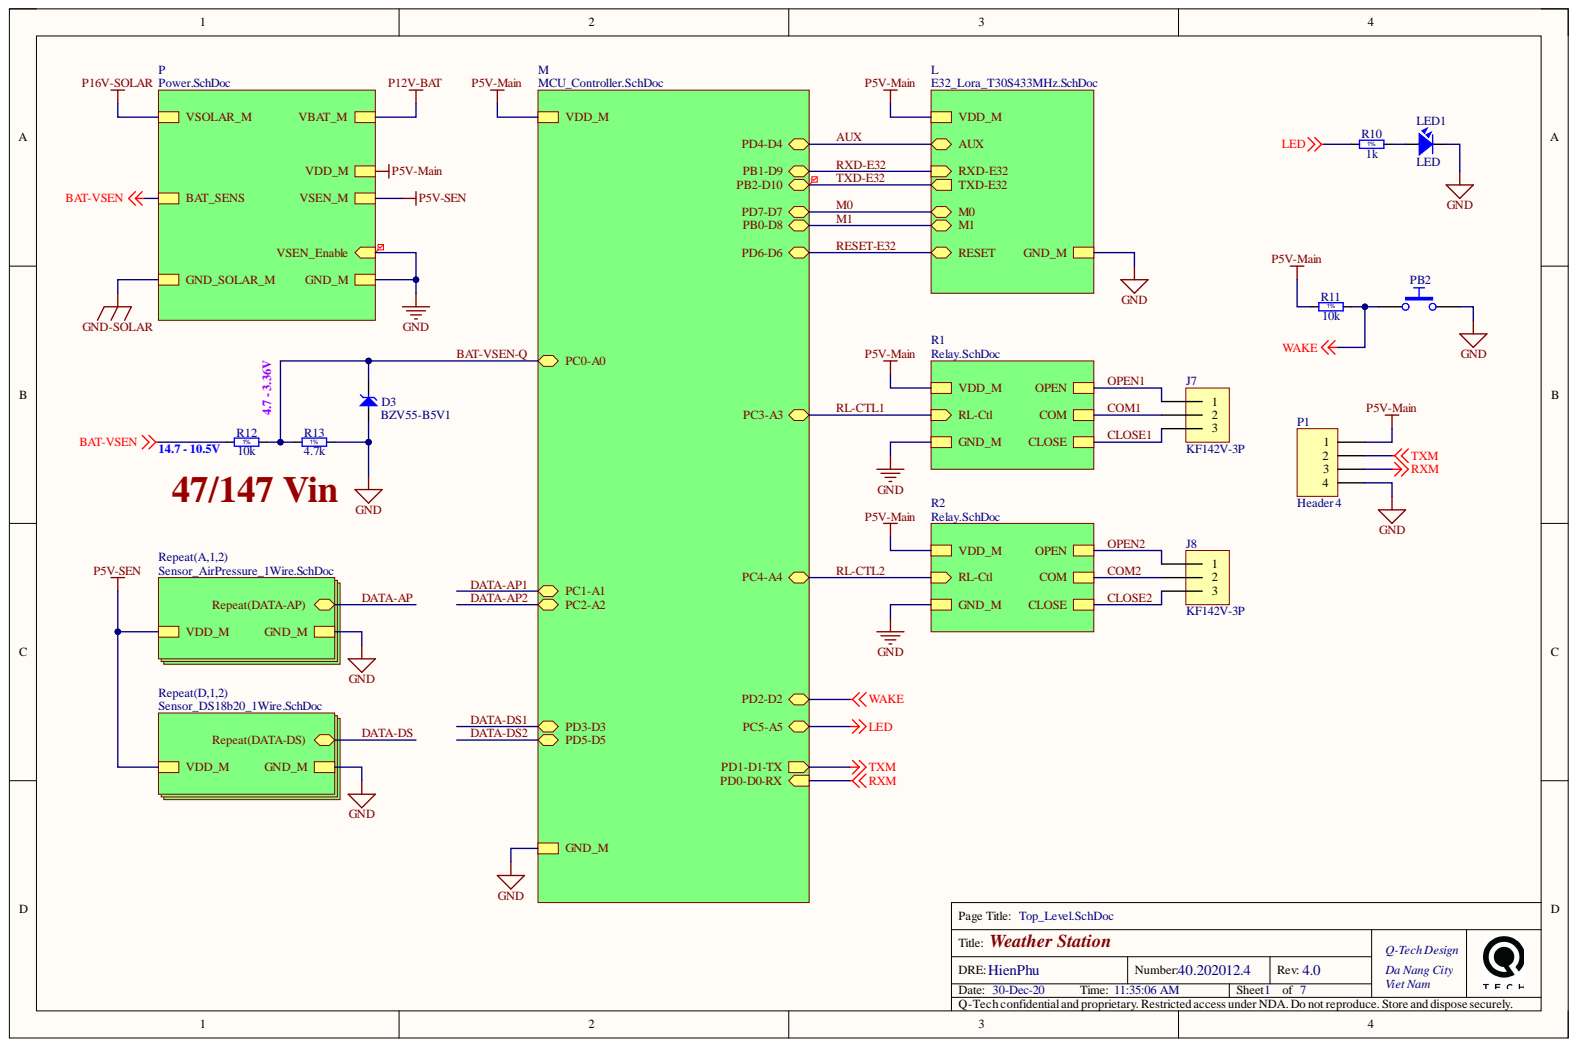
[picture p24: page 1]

COM1 | 1 2 3

Weather Station Title: | Q-Tech Design Da Nang City

DRE:HienPhu | Number: 40.202012.4 | Rev: 4.0
Date: 30-Dec-20 Time: 11:35:06 AM | Sheet 1 of | Viet Nam 7

Q-Tech confidentialand proprietary. Restricted access under NDA. Do not reproduce. Store and dispose securely.

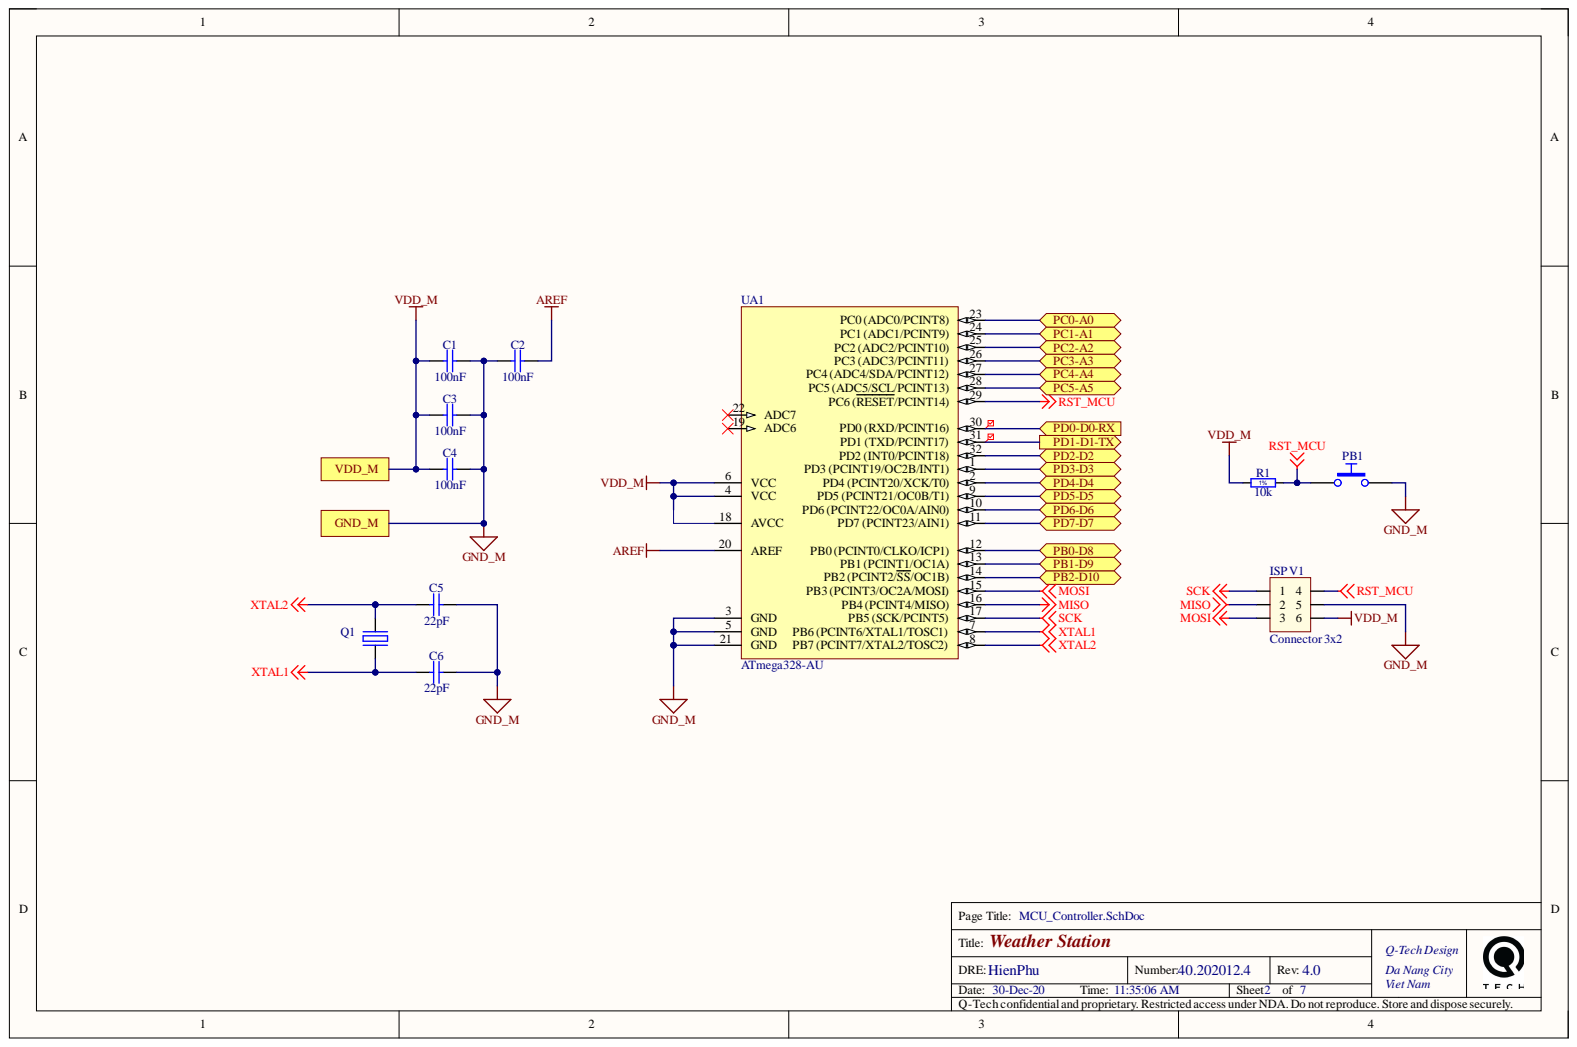
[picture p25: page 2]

Weather Stat ion Titl e : | Q-Te ch De sig n Da Nang C ity Vi et Nam

DRE: H ien P hu | Numbe r : 4 0.2 0 2 0 1 2 . 4 | R e v : 4 . 0

Date : 30-De c -2 0 Time : 11:35:06 AM | She e t 2 of 7

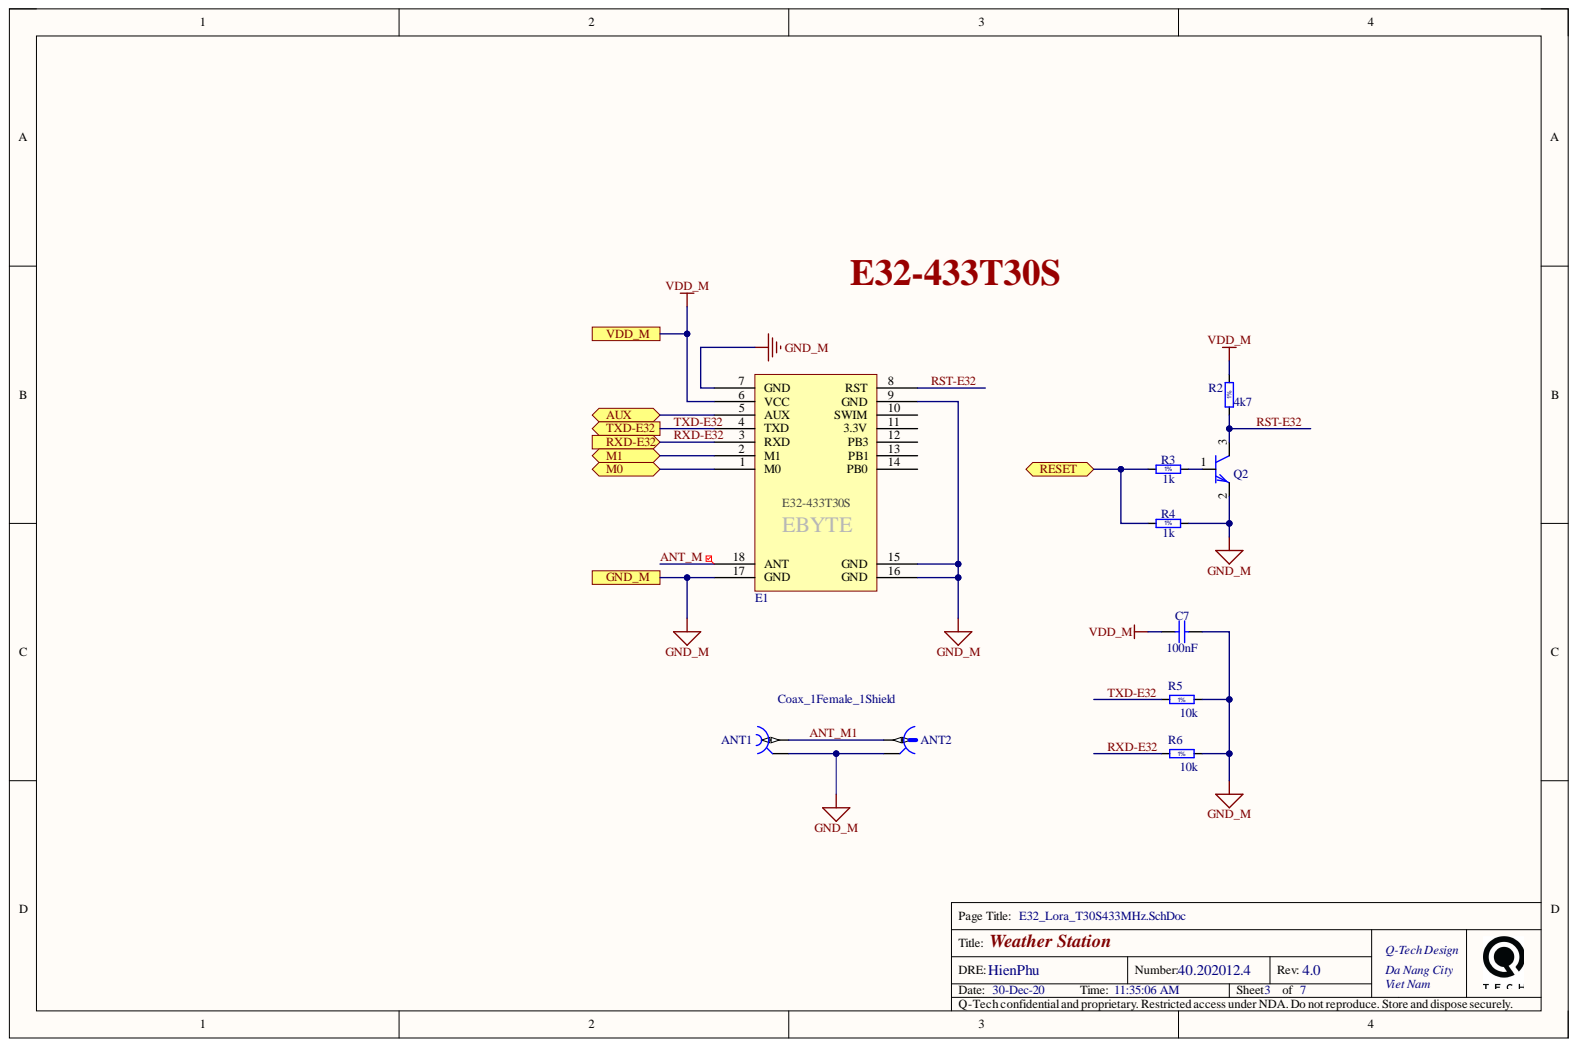
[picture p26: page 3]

1% | GND_M

Weather Station Title: | Q-Tech Design Da Nang City

DRE:HienPhu | Number: 40.202012.4 | Rev: 4.0
Date: 30-Dec-20 Time: 11:35:06 AM | Sheet 3 of | Viet Nam 7

Q-Tech confidentialand proprietary. Restricted access under NDA. Do not reproduce. Store and dispose securely.

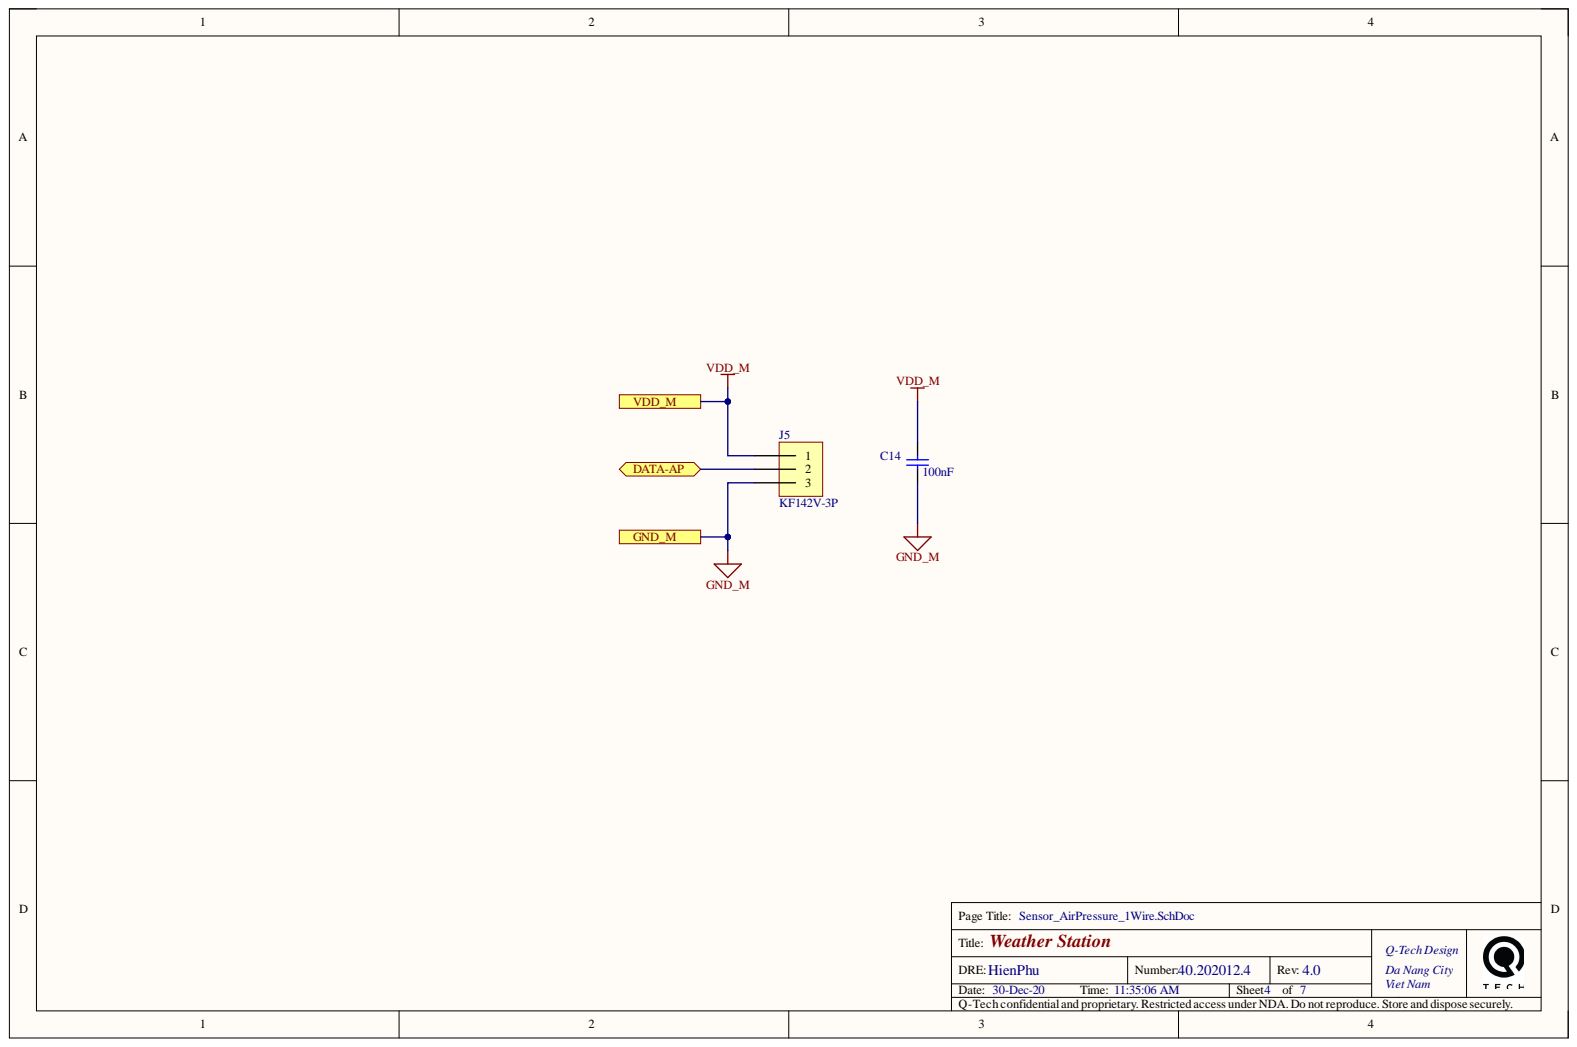
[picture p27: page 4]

Weather Station Title: | Q-Tech Design Da Nang City

DRE:HienPhu | Number: 40.202012.4 | Rev: 4.0
Date: 30-Dec-20 Time: 11:35:06 AM | Sheet 4 of | Viet Nam 7

Q-Tech confidentialand proprietary. Restricted access under NDA. Do not reproduce. Store and dispose securely.

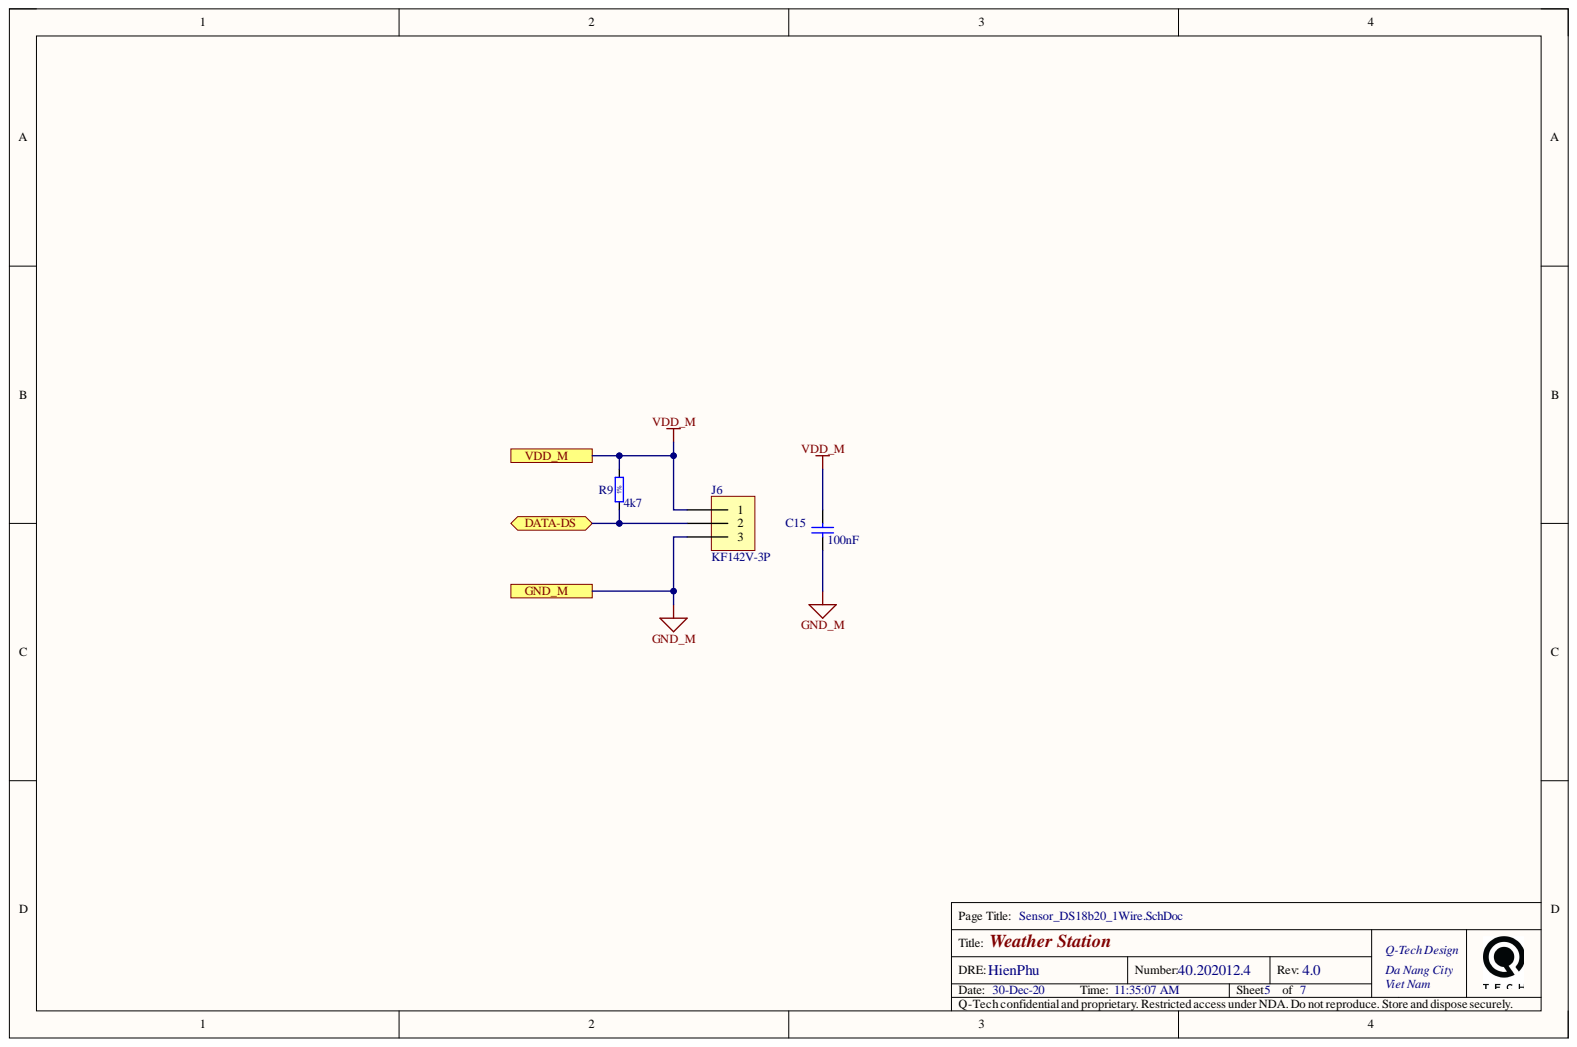
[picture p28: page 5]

Weather Station Title: | Q-Tech Design Da Nang City

DRE:HienPhu | Number: 40.202012.4 | Rev: 4.0
Date: 30-Dec-20 Time: 11:35:07 AM | Sheet 5 of | Viet Nam 7

Q-Tech confidentialand proprietary. Restricted access under NDA. Do not reproduce. Store and dispose securely.

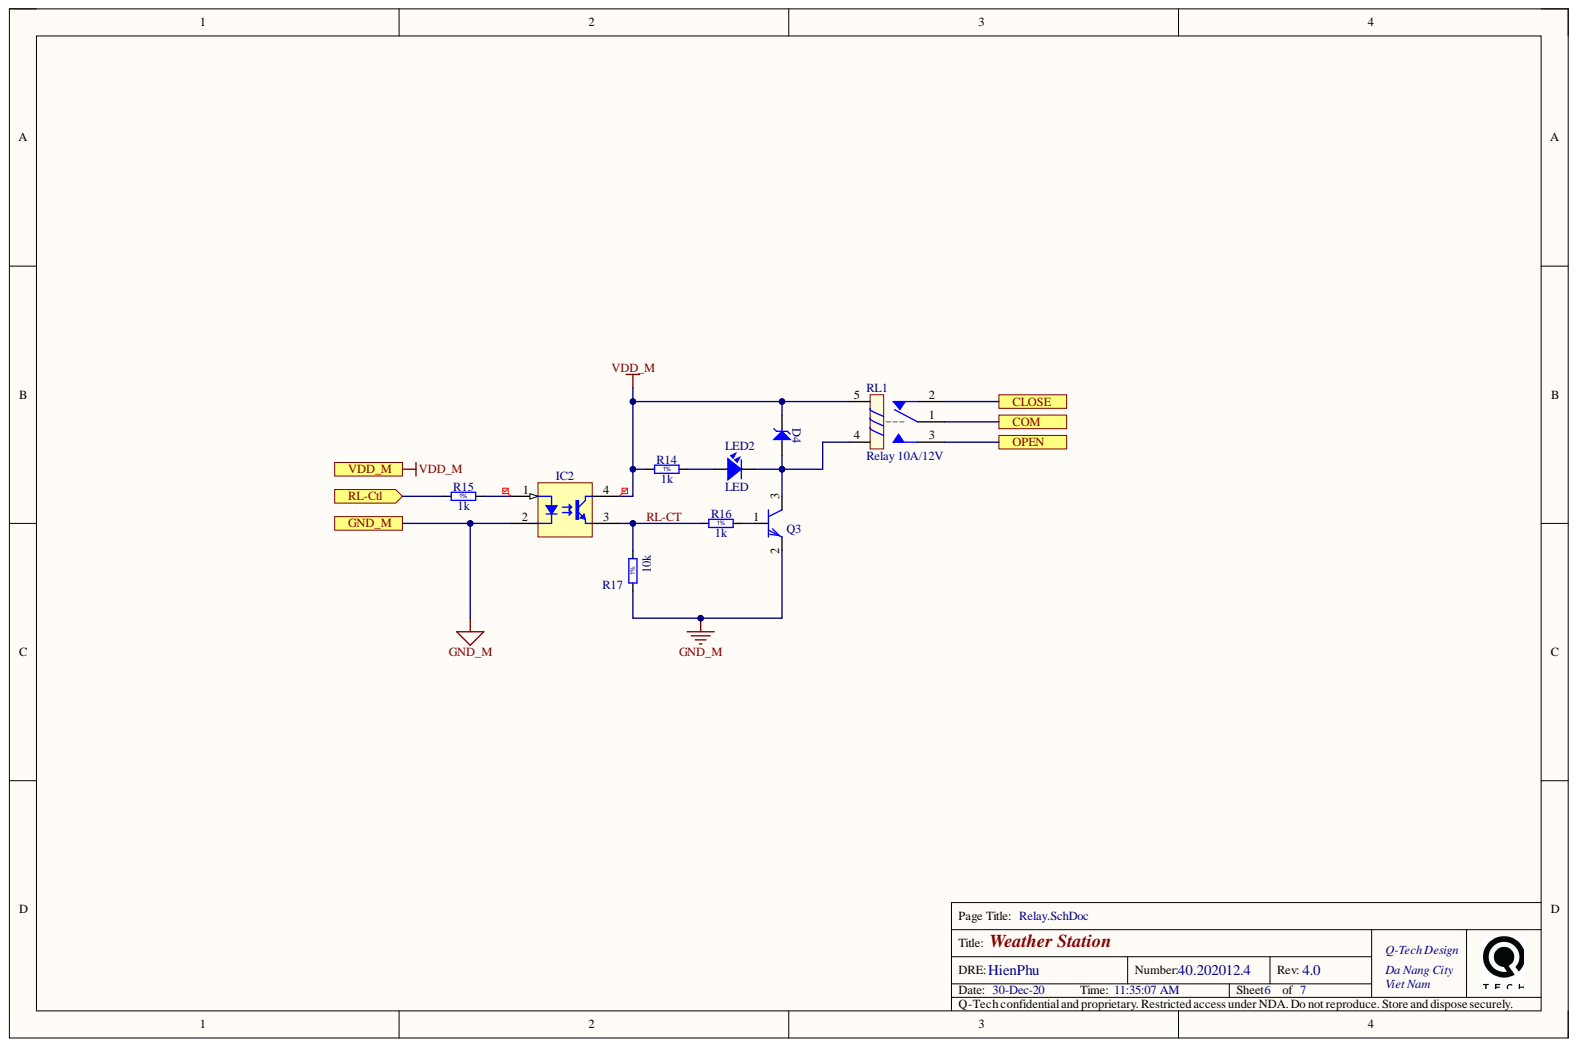
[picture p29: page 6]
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

Date : 30-De c -2 0 Time : 11:35:07 AM | She e t 6 of 7

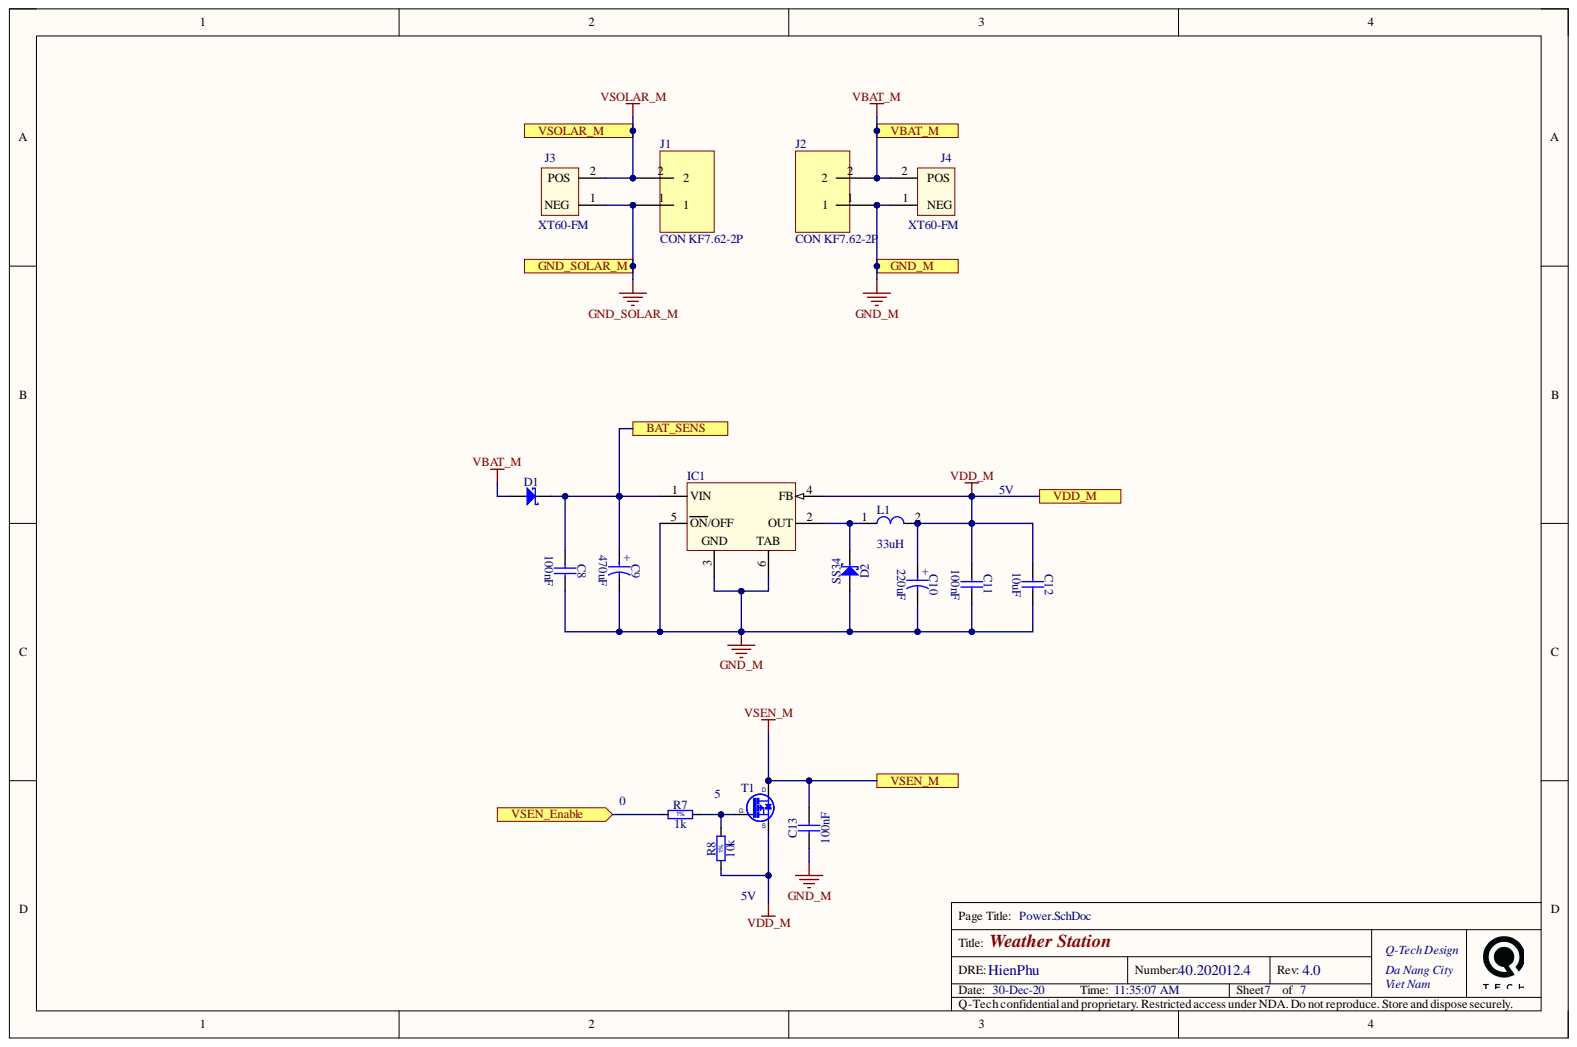
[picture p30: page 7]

GND

Page Title: Power.SchDoc

Weather Station Title: | Q-Tech Design Da Nang City

DRE:HienPhu | Number: 40.202012.4 | Rev: 4.0
Date: 30-Dec-20 Time: 11:35:07 AM | Sheet 7 of | Viet Nam 7

Q-Tech confidentialand proprietary. Restricted access under NDA. Do not reproduce. Store and dispose securely.

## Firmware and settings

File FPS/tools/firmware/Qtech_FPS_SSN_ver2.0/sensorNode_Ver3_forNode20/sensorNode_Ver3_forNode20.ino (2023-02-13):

#include "LowPower.h"
#include "UDOpenLora.h"
#include <EEPROM.h>
#include <Arduino.h>
#include <avr/wdt.h>

/**************************
 * define EPPROM address
**************************/
const int networkState_EEP = 0;         //1 bytes
const int networkAddrH_EEP = 1;         //1 bytes
const int networkAddrL_EEP = 2;         //1 bytes
const int networkChanel_EEP = 3;        //1 bytes
const int timeSendDataLoop_MIN_EEP = 4; //1 bytes
const int secondUploadFirmware_EEP = 5; //1 bytes
const int networkKey_EEP = 20;          //3 bytes

/**************************
 * config for device
**************************/
bool enableDebugPort = false;
bool reWriteEEPROM = false;
int secondUploadFirmware = 0;


const char markMess_SensorNode[4] = {0xD2, 0xD3, 0xD3, '\0'};
const String device_serial_key = "SENOqGEkdiyGhj3ROp0S";

/**************************
 * setup for lora
**************************/
#define lora_power TSMT_PWR_30DB
#define loraSerial Serial2
UDOpenLora loraBoard(&loraSerial);
const int loraUAXPin = 3;
const int M0Pin = 7;
const int M1Pin = 6;

int networkState = 0;
int networkAddrH = 0x14;
int networkAddrL = 0x12;
int networkChanel = 0x19;  
char networkKey[4];  

char data_buf[128];
char send_buf[128];
uint8_t data_len;
byte ADDR_H, ADDR_L;

const char configLoraIDHeader[4] = {0xA2, 0xA1, 0xA3, '\0'};
const char leaveNetworkHeader[4] = {0xA2, 0xA1, 0xA2, '\0'};
const char configTimerUpdateHeader[4] = {0xA2, 0xA4, 0xA3, '\0'};
const char updateDataHeader[4] = {0xB2, 0xB1, 0xB0, '\0'};
const char UpdateDataHeader_ACK[4] = {0xB2, 0xB2, 0xB2, '\0'};
const char actionToNodeHeader[4] = {0xB9, 0xB8, 0xB9, '\0'};
const char requestToRebootHeader[4] = {0xB2, 0xB0, 0xB3, '\0'};

/**************************
 * config for lora mess loop
**************************/
bool gotACK = false;
char ACKValue = 0;
int updateStateTimeout_Sec = 5;
unsigned long lastMessageTime = 0;
int timeSendDataLoop_MIN = 0;

/**************************
 * config PINS
**************************/
const int led_R = 38; // turn on : 0; turn off : 1;
const int led_G = 37;

const int buttonPin = 2;


unsigned long timeCheckReset = 0;
unsigned long timeForReset_DAY = 1; //max in 5 days
int timesWakeup = 0;
bool isLoraWakeup = false;
bool isButtonWakeup = false;
bool isTimerWake = true;


/**************************
 * MAIN
**************************/
void setup()
{
  if(enableDebugPort == true)
  {
    Serial.begin(9600);
    Serial.print("device_serial_key: "); 
    Serial.println(device_serial_key); 
  }  
  setupLora();
  setupSensors();
  setupForDevice(); // empty funtion
  turnOnInterrupt();
  setupLedDebug();
  blinkDebugLed(2, 500);
}

void loop() 
{    
  loopBegin:
  gotoSleepMode();  
  if(enableDebugPort == true)
  {
    Serial.println("//************"); 
    Serial.println("wake up\n"); 
  }
  checkLoraWakeUp();
  checkButtonWakeUp();
  if(isTimerWake == false)
  {
    isTimerWake = true;
    if(loraSerial.available() > 0)
    {  
      while(loraSerial.available() > 0)
      {
        if(enableDebugPort == true)      
        {
          Serial.write(loraSerial.read());
        }
      }
    }  
    goto loopBegin;
  }
  checkTimerWakeUp(); 
  if(enableDebugPort == true)
  {
    delay(200);
  }
  else
  {
    delay(10);
  }
}
//********************************************************


/**************************
 * LORA functions
**************************/
void setupLora()
{     
  handleEPPROMReader();
  if(enableDebugPort == true)
  {
    HardwareSerial* debugSerial = &Serial;
    loraBoard.setDebugPort(debugSerial); 
  }
  loraSerial.begin(9600);  
  readNetworkConfig();
  loraBoard.setIOPin(M0Pin, M1Pin, loraUAXPin);
  delay(1000);
  loraBoard.LoraBegin((byte)(networkAddrH), (byte)(networkAddrL), (byte)(networkChanel), lora_power);  
  delay(1000);
  while(loraSerial.available() > 0)
  {       
    if(enableDebugPort == true)
    {
      Serial.println(loraSerial.read(), DEC);
    }
    else
    {
      loraSerial.read();
    }
  }  
  if(enableDebugPort == true)
  {
    sendMessageToGateway("Setup done.");
  }
}

void handleEPPROMReader()
{
  if(reWriteEEPROM == true)
  {   
    if(enableDebugPort == true)
    { 
      Serial.println("re Write EEPROM secondUploadFirmware = 0");
    }
    EEPROM.write(secondUploadFirmware_EEP, 0);
  }   
  secondUploadFirmware = EEPROM.read(secondUploadFirmware_EEP);  
  if(secondUploadFirmware == 0)
  {
    if(enableDebugPort == true)
    { 
      Serial.println("first Upload Firmware");
    }
    EEPROM.write(networkState_EEP, networkState);
    EEPROM.write(networkAddrH_EEP, networkAddrH);
    EEPROM.write(networkAddrL_EEP, networkAddrL);
    EEPROM.write(networkChanel_EEP, networkChanel);
    EEPROM.write(timeSendDataLoop_MIN_EEP, 3);
    EEPROM.write(secondUploadFirmware_EEP, 1); // variable for write epprom again or not
  }
}

void sendMessageToGateway(String mess)
{
  turnOffInterrupt();  
  memset(send_buf, '\0', 128);
  mess.toCharArray(send_buf, 256);
  loraBoard.SendMessage(0x00, 0x00, send_buf);
  blinkDebugLed(2, 150);
  turnOnInterrupt();
}

void configLoraID(char data_buf[], int data_len)
{  
  char serial_key[21];
  strncpy(serial_key, data_buf + 3, 20);
  serial_key[20] = '\0';
  char netKey[3];
  strncpy(netKey, data_buf + 23, 3);
  networkAddrH = data_buf[26];
  networkAddrL = data_buf[27];
  networkChanel = data_buf[28];   
  if(enableDebugPort == true)
  {          
    Serial.print("NEW serial_key: ");  
    Serial.println(serial_key);    
    Serial.println(netKey);
    Serial.print("NEW ID: 0x");  
    Serial.print(networkAddrH, HEX);    
    Serial.println(networkAddrL, HEX);
    Serial.print("NEW networkChanel: 0x");  
    Serial.println(networkChanel, HEX);
  }
  if(String(serial_key) == device_serial_key)
  {
    saveNetworkData(networkAddrH, networkAddrL, networkChanel, netKey); 
    delay(200);
    loraBoard.LoraBegin((byte)(networkAddrH), (byte)(networkAddrL), (byte)(networkChanel), lora_power);
    delay(1500);
    if(loraSerial.available() > 0)
    {       
      if(enableDebugPort == true)
      {
        Serial.println(loraSerial.read(), DEC);
      }
      else
      {
        loraSerial.read();
      }
    }  
    delay(1500);
    if(enableDebugPort == true)
    {
      sendMessageToGateway("Setup new ID done.");
    }
  }
}

void processingLoraMessage(char data_buf[], int data_len)
{
  clearDataBuf();
  if(strstr(data_buf, configLoraIDHeader))
  {
    configLoraID(data_buf, data_len);
  }
  else
  {  
    if(networkState == 1)
    {
      if(strstr(data_buf, networkKey))
      {
        if(strstr(data_buf, updateDataHeader))
        {
          sendDataToCloud();
        }
        else if(strstr(data_buf, UpdateDataHeader_ACK))
              {                
                receiveACK();
              }
              else if(strstr(data_buf, configTimerUpdateHeader))
                    {
                      configTimerUpdate();
                    }
                    else if(strstr(data_buf, requestToRebootHeader))
                        {
                          rebootDevice();
                        }
                        else if(strstr(data_buf, leaveNetworkHeader))
                            {
                              leaveNetwork();
                            }
      }
    }
  }
}

void clearDataBuf()
{
  int idx = 0;
  for(int i = 0; i < data_len; i++)
  {
    if(data_buf[i] != '\0')
    {
      idx = i;
      if(enableDebugPort == true)
      { 
        Serial.print("idx: ");
        Serial.println(idx);
      }
      break;
    }
  }
  for(int i = 0; i < data_len; i++)
  {
    data_buf[i] = data_buf[i+idx];
  }
  printLoraMess(data_buf, data_len);
}

void leaveNetwork()
{
  networkState = 0;
  if(enableDebugPort == true)
  {   
    Serial.println("leaveNetwork...");
    Serial.print("networkState: ");
    Serial.println(networkState);
  }
  EEPROM.write(networkState_EEP, networkState);
}

void rebootDevice()
{
  if(enableDebugPort == true)
  {
    Serial.println("Reseting...");
    delay(100);
//    wdt_enable(WDTO_30MS);
//    delay(10000);
  }
}


void configTimerUpdate()
{
  timeSendDataLoop_MIN = int(data_buf[6]);
  EEPROM.write(timeSendDataLoop_MIN_EEP, timeSendDataLoop_MIN);
  if(enableDebugPort == true)
  {
    Serial.println("configTimerUpdate");
    Serial.println(timeSendDataLoop_MIN);
  }
}

void receiveACK()
{
  if(enableDebugPort == true)
  {
    Serial.println("receiveACK");
  }
  if(gotACK == false)
  {
    char ACK_Receive = data_buf[6];
    if(enableDebugPort == true)
    {
      Serial.print("ACK_Receive: ");
      Serial.println(ACK_Receive, HEX);
      Serial.print("ACKValue: ");
      Serial.println(ACKValue, HEX);
    }
    if(ACK_Receive == ACKValue)
    {
      gotACK = true;
      if(enableDebugPort == true)
      {
        Serial.print("gotACK: ");
        Serial.println(gotACK);
      }
    }
  }
  
}

void sendDataToCloud()
{  
  if(enableDebugPort == true)
  {
    Serial.println("sendDataToCloud");
  }
  sendSensorMessData();
  gotACK = false;  
  if(enableDebugPort == true)
  {
    Serial.print("gotACK: ");
    Serial.println(gotACK);
  }
  timesWakeup = 0;
}

void printLoraMess(char data_buf[], int data_len)
{  
  if(enableDebugPort == true)
  {
    Serial.print("message: ");
    for(int idx=0;idx<data_len;idx++)
    {
      Serial.print(char(data_buf[idx]));
    } 
    Serial.println("");
    Serial.print("HEX: ");
    for(int idx=0;idx<data_len;idx++)
    {
      Serial.print(byte(data_buf[idx]), HEX);
      Serial.print(":");
    } 
    Serial.println("");
  }
}

void saveNetworkData(uint8_t AH, uint8_t AL, uint8_t CN, char netKey[])
{
  networkState = 1;
  networkKey[0] = netKey[0];
  networkKey[1] = netKey[1];
  networkKey[2] = netKey[2];
  networkKey[3] = '\0';
  EEPROM.write(networkState_EEP, 1);
  EEPROM.write(networkAddrH_EEP, AH);
  EEPROM.write(networkAddrL_EEP, AL);
  EEPROM.write(networkChanel_EEP, CN);
  for(int i = 0; i <= 3; i++)
  {
    EEPROM.write((networkKey_EEP + i), networkKey[i]);
  }
  if(enableDebugPort == true)
  { 
    Serial.print("networkState: ");
    Serial.println(networkState);
  }
}

void readNetworkConfig()
{  
  networkState = EEPROM.read(networkState_EEP);    
  networkAddrH = EEPROM.read(networkAddrH_EEP);
  networkAddrL = EEPROM.read(networkAddrL_EEP);
  networkChanel = EEPROM.read(networkChanel_EEP);  
  timeSendDataLoop_MIN = EEPROM.read(timeSendDataLoop_MIN_EEP);  
  for(int i = 0; i <= 3; i++)
  {
    networkKey[i] = EEPROM.read(networkKey_EEP + i); 
  }
  if(enableDebugPort == true)
  {
    Serial.print("networkState: ");    
    Serial.println(networkState);
    Serial.print("networkAddrH: ");    
    Serial.println(networkAddrH, HEX);
    Serial.print("networkAddrL: ");    
    Serial.println(networkAddrL, HEX);
    Serial.print("timeSendDataLoop_MIN: ");    
    Serial.println(timeSendDataLoop_MIN);
    Serial.print("networkKey: ");    
    Serial.println(networkKey);
  }
}


/**************************
 * Sleep handle function
**************************/
void checkButtonWakeUp()
{ 
  if(isButtonWakeup == true)
  {     
    delay(50);
    if(digitalRead(buttonPin) == LOW)
    {
      while(digitalRead(buttonPin) == LOW);
    }
    else
    {
      return;
    }
    sendDataToCloud();
    isButtonWakeup = false;
    isTimerWake = false;
    turnOnInterrupt();
  }
}

void checkLoraWakeUp()
{   
  if(isLoraWakeup == true)
  {     
    delay(100);
    while(digitalRead(buttonPin) == LOW){};
    while(loraSerial.available() < 0)
    {    
      delay(50);
      if(enableDebugPort == true)
      {
        Serial.println(".");
      }
    }
    delay(100);
    if(loraBoard.ReceiveMsg(&ADDR_H, &ADDR_H, data_buf, &data_len)==RET_SUCCESS)
    {  
      blinkDebugLed(2, 200);
      printLoraMess(data_buf, data_len);
      processingLoraMessage(data_buf, data_len);        
    }  
    delay(500);
    isLoraWakeup = false;
    isTimerWake = false;
    turnOnInterrupt();
  }
}

void processingTimerLoop()
{  
  delay(50);
  if(loraSerial.available() > 0)
  {  
    while(loraSerial.available() > 0)
    {
      Serial.write(loraSerial.read());
    }
  }  
  timesWakeup++;
  timeCheckReset++;
  if(enableDebugPort == true)
  {
    Serial.println(timesWakeup);
  }  
//  if((timeCheckReset) >= (timeForReset_DAY*(60*60/8))) //change to reset every 3h
////  if((timeCheckReset) >= (timeForReset_DAY*(30/8))) //change to reset every 3h
//  {    
//    blinkDebugLed(5, 50);
//    rebootDevice();
//  }
  if(networkState == 1)
  {
    if((timesWakeup*8) >= (timeSendDataLoop_MIN*60))
    {    
      sendDataToCloud();
    }
    else if(((timesWakeup*8) >= updateStateTimeout_Sec) && (gotACK == false))
          {    
            sendDataToCloud();
          }
  }
}

void checkTimerWakeUp()
{
  turnOffInterrupt();
  processingTimerLoop();
  turnOnInterrupt();
}

void wakeUpByButton()
{
  turnOffInterrupt();
  if(enableDebugPort == true)
  {
    Serial.println("Wake up by Button.");
  } 
  isButtonWakeup = true;     
}

void wakeUpByLora()
{
  turnOffInterrupt();   
  if(enableDebugPort == true)
  {
    Serial.println("Wake up by lora.");
  }   
  delay(50);
  isLoraWakeup = true;
}

void gotoSleepMode()
{  
  turnOffInterrupt(); 
  if(enableDebugPort == true)
  {
    Serial.println("Sleep\n");
    delay(80);
  }
  turnOnInterrupt();
  LowPower.powerDown(SLEEP_8S, ADC_OFF, BOD_OFF);  
}

void turnOffInterrupt()
{
  detachInterrupt(0);
  detachInterrupt(1);
}

void turnOnInterrupt()
{  
  attachInterrupt(0, wakeUpByButton, LOW);
  attachInterrupt(1, wakeUpByLora, LOW);
}


/**************************
 * function per device
**************************/
char SensorData = "";

void setupForDevice()
{  
}

void sendSensorMessData()
{
  if(networkState == 1)
  {
    char SendBuf[128];
    memset(SendBuf, '\0', 128);
    int lengthMess = 0;    
    String messSend = networkKey + String(markMess_SensorNode) + getAllSensorData_String();
    ACKValue = messSend.length();
    messSend = messSend + char(ACKValue);
    sendMessageToGateway(messSend);
  }
  lastMessageTime = millis();
}


/**************************
 * Support TEST functions
**************************/
void setupLedDebug()
{
  pinMode(led_R, OUTPUT);
  pinMode(led_G, OUTPUT);

  digitalWrite(led_R, HIGH);
  digitalWrite(led_G, HIGH);

}

void blinkDebugLed(int times, int timeDelay)
{
  for(int i = 0; i < times; i++)
  {          
    digitalWrite(led_R, LOW);
    delay(timeDelay/2);
    digitalWrite(led_R, HIGH);
    delay(timeDelay/2);
    digitalWrite(led_G, LOW);
    delay(timeDelay/2);
    digitalWrite(led_G, HIGH);
    delay(timeDelay/2);
  }     
}

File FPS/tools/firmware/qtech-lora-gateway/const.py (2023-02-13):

import json
import random

mainpath = "/home/pi/qtech-lora-gateway/"

#Log file
logPath = ("%sLOG.CSV" %mainpath)

# data file
logPath = ("%sLOG.CSV" %mainpath)
fileName = ("%sDATA.CSV" %mainpath)
maxData = 256     # num of end device can join to lora mesh


configFilePath = "/home/pi/qtech-lora-gateway/config.json"
try:
    with open(configFilePath) as f:
        data = json.load(f)
except:
    print('CREATE NEW config.json FILE')
    f = open(configFilePath,"w+") 
    f.write("{\n\"hubID\": \"GATE_COOR_123457890\"\n}")
    with open(configFilePath) as f:
        data = json.load(f)

hubID = str(data['hubID'])
netKey = hubID[10:13]
print(hubID)
print(netKey)

databaseURL =  'https://qtech-protection-system.firebaseio.com/'
firebaseCertFile = ("%sDB_Token.json" %mainpath)

print('databaseURL', databaseURL)
print('firebaseCertFile', firebaseCertFile)




timeLimit2PING = 60
timeLimit2SendPING = 1.5
offlineTimeout = 5
timeLimitAcceptJoin = 30

# define the special symbol in Lora messages 
# define the special symbol in Lora messages 
HUB_LORA_ID                   = '0000'
HUB_lora_chanel               = '19'
endMessSymbol                 = 'AB'

leaveNetworkHeader            = 'A2A1A2'
configLoraIDHeader            = 'A2A1A3'
configTimerUpdateHeader       = 'A2A4A3'
sendUpdateHeader              = 'B0B1B0'
UpdateDataHeader_ACK          = 'B2B2B2'
requestToUpdateDataHeader     = 'B2B1B0'

requestToRebootHeader         = 'B2B0B3'
actionToNodeHeader            = 'B9B8B9'
# mark
markMess_ValvesController     = 'D1D3D2'
markMess_SensorNode           = 'D2D3D3'

#firebase Header
controlDevice_firebaseCommand     = 'controlDevice'
refresh_firebaseCommand           = 'F5_Data'
configTimerUpdate_firebaseCommand = 'configTimer'
updateDevice_firebaseCommand      = 'UPDevice'
removeDeivce_firebaseCommand      = 'removeDevice'
updateSourceCode_firebaseCommand  = 'upSource'
rebootRequest_firebaseCommand     = 'reboot'


# convert from string to bytes
Str_HUB_LORA_ID                = (bytes.fromhex(HUB_LORA_ID)).decode(encoding = 'cp855', errors='strict')
Str_HUB_lora_chanel            = (bytes.fromhex(HUB_lora_chanel)).decode(encoding = 'cp855', errors='strict')
Str_endMessSymbol              = (bytes.fromhex(endMessSymbol)).decode(encoding = 'cp855', errors='strict')

Str_leaveNetworkHeader         = (bytes.fromhex(leaveNetworkHeader)).decode(encoding = 'cp855', errors='strict')
Str_configLoraIDHeader         = (bytes.fromhex(configLoraIDHeader)).decode(encoding = 'cp855', errors='strict')
Str_configTimerUpdateHeader    = (bytes.fromhex(configTimerUpdateHeader)).decode(encoding = 'cp855', errors='strict')
Str_sendUpdateHeader           = (bytes.fromhex(sendUpdateHeader)).decode(encoding = 'cp855', errors='strict')
Str_UpdateDataHeader_ACK       = (bytes.fromhex(UpdateDataHeader_ACK)).decode(encoding = 'cp855', errors='strict')
Str_requestToUpdateDataHeader  = (bytes.fromhex(requestToUpdateDataHeader)).decode(encoding = 'cp855', errors='strict')
Str_requestToRebootHeader      = (bytes.fromhex(requestToRebootHeader)).decode(encoding = 'cp855', errors='strict')
Str_actionToNodeHeader         = (bytes.fromhex(actionToNodeHeader)).decode(encoding = 'cp855', errors='strict')

Str_markMess_ValvesController  = (bytes.fromhex(markMess_ValvesController)).decode(encoding = 'cp855', errors='strict')
Str_markMess_SensorNode        = (bytes.fromhex(markMess_SensorNode)).decode(encoding = 'cp855', errors='strict')

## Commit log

2023-02-13 public android code
    [activity_app_info.xml, app_bar_main2.xml, bg_btn_app_green.xml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]
2025-08-10 Create PCB
2025-08-10 Qtech 3.0
    [E32_Lora_T20S868MHz.SchDoc, E32_Lora_T30S433MHz.SchDoc, Hardware.SchDoc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]
2025-08-10 docs(hardware): add PCB build index and assembly notes for Qtech 3.0
2025-08-10 docs(hardware): add calibration guide and hardware README; link album from PCB
